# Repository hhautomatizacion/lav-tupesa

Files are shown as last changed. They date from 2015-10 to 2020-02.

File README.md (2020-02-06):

<br/>
<p align="center">
  
</p>
<br/>

# lav-tupesa

## Fecha 
* 2015

## Descripcion del proyecto
* Control de lavadora industrial tupesa 190

## Herramientas utilizadas
* KGL_WIN version 3.66
* DopSoft version 1.01.08

## Modelos PLC, etc.
* PLC LS Master K 120S K7M-DR40U
* HMI Delta DOP B05S111 
* Modulo Analogo G7F-R2D

## Autores
* <a href="http://www.github.com/pedrohermon">pedrohermon</a> 
* <a href="http://www.github.com/emmanuel156">emmanuel156</a> 

## Comentarios
* Ninguno

## Contenido
* Carpeta de Diagramas
	* Diagramas del proyecto
		* Diagramas electricos
		* Diagramas de bloques
		* Dibujos
* Carpeta de Documentos
	* Documentos pensados para el usuario final
		* Manuales de usuario
		* Manuales de programacion
* Carpeta de Fotos
	* Fotos del proyecto antes, durante y despues del desarrollo del mismo
		* Fotos
		* Capturas de pantalla
* Carpeta de Historial
	* Documentacion del desarrollo del proyecto
		* Hojas de datos de componentes
		* Manuales de usuario de componentes
		* Documentacion de funciones, herramientas
* Carpeta de Programas
	* Programas de Computadora, PLC, etc. 
		* Codigos fuente
		* Iconos e imagenes usados en los programas 
		* Archivos de configuracion de los programas
		* Programas compilados
* Carpeta de Pruebas
	* Pruebas preliminares del proyecto
		* Programas incompletos, o secciones de programas
		* Capturas de comunicacion
		* Modelos de componentes que se hayan probado

---
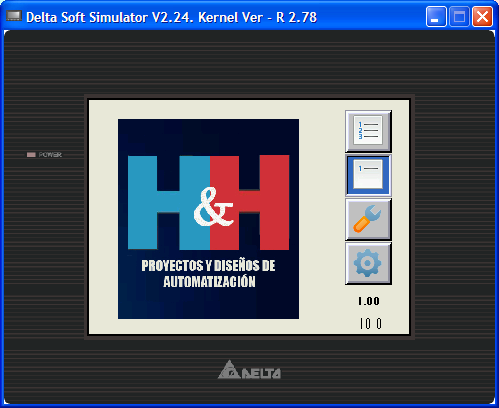
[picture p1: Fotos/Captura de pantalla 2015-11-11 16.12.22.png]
Captura de pantalla 2015-11-11 16.12.22.png

---
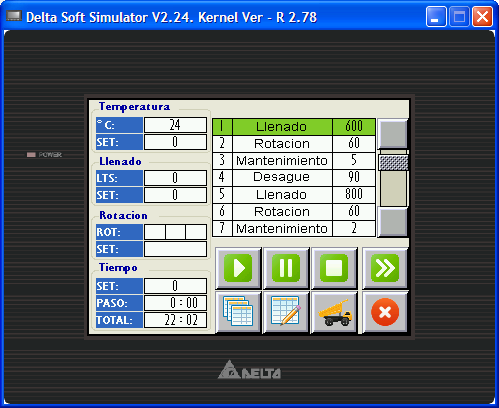
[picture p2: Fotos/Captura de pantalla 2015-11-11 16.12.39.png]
Captura de pantalla 2015-11-11 16.12.39.png

---
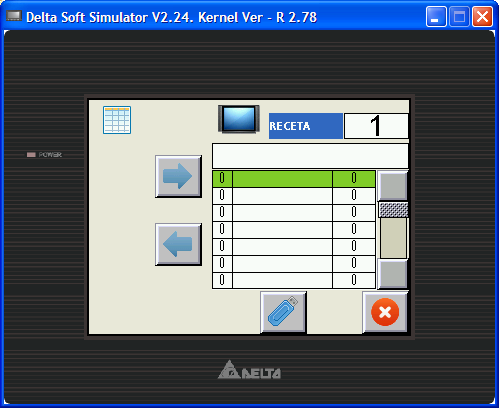
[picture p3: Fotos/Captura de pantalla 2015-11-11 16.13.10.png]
Captura de pantalla 2015-11-11 16.13.10.png

---
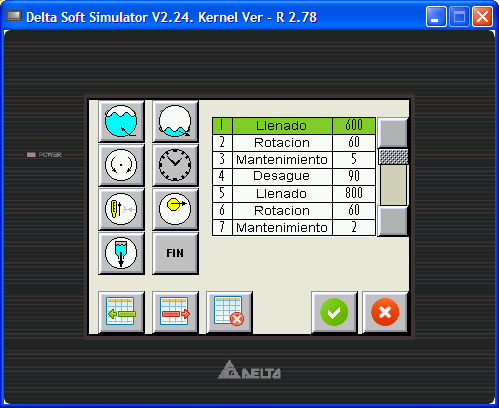
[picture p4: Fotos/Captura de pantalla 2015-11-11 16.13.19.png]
Captura de pantalla 2015-11-11 16.13.19.png

---
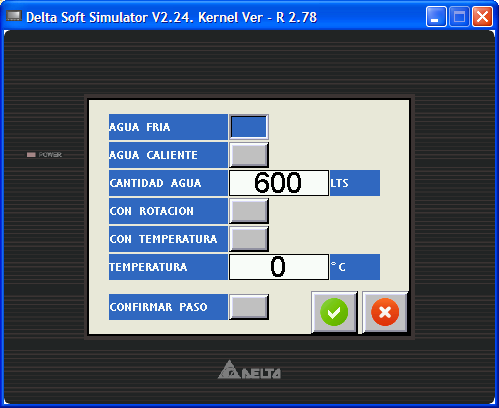
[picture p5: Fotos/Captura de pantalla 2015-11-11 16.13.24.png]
Captura de pantalla 2015-11-11 16.13.24.png

---
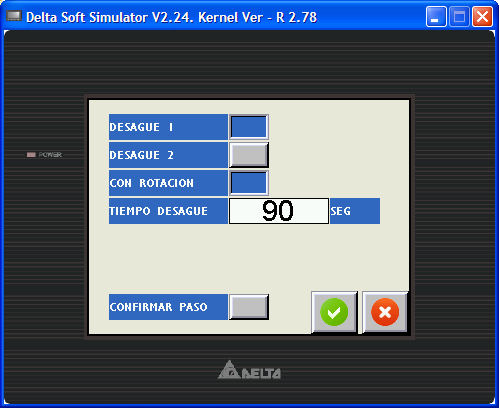
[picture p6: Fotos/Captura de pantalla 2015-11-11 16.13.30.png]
Captura de pantalla 2015-11-11 16.13.30.png

---
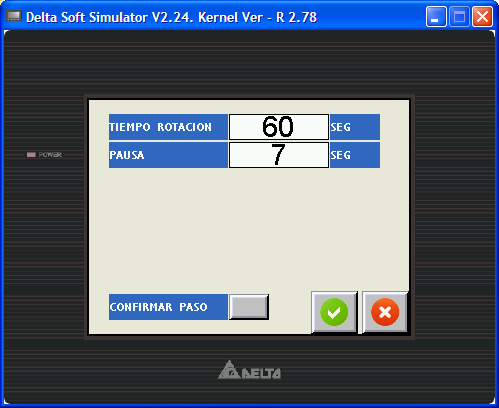
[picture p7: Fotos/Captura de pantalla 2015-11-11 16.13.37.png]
Captura de pantalla 2015-11-11 16.13.37.png

---
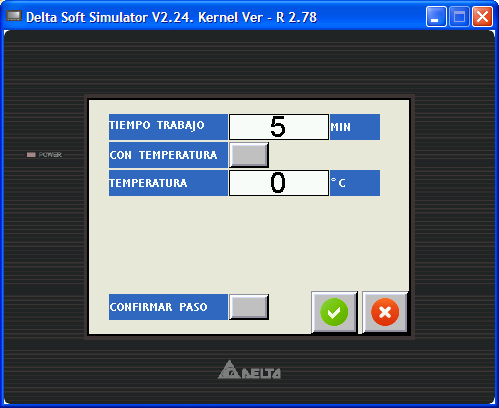
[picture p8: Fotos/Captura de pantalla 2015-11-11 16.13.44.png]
Captura de pantalla 2015-11-11 16.13.44.png

---
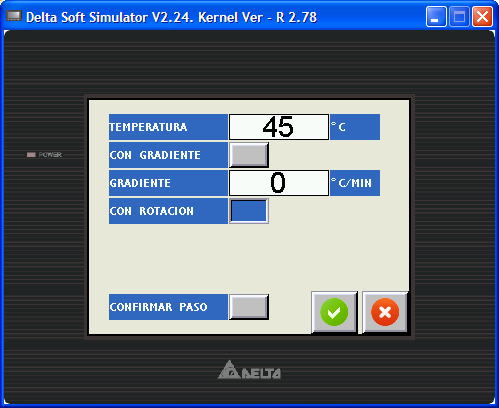
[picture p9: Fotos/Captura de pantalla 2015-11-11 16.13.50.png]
Captura de pantalla 2015-11-11 16.13.50.png

---
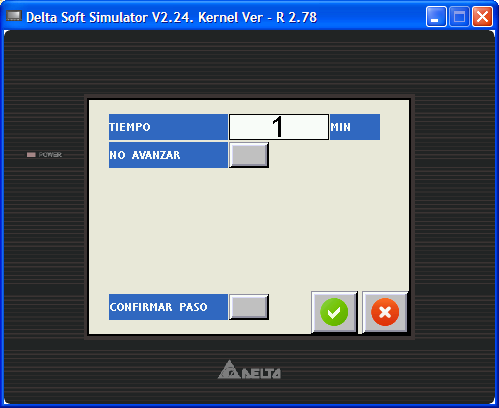
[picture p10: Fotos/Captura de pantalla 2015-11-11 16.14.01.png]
Captura de pantalla 2015-11-11 16.14.01.png

---
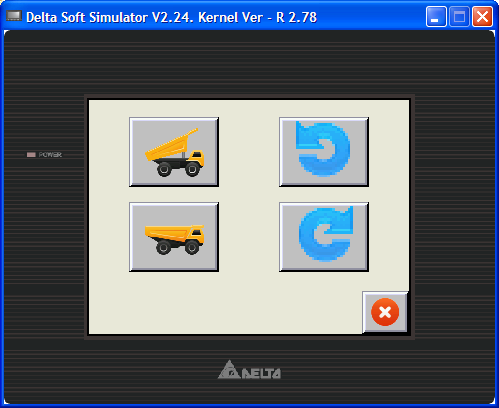
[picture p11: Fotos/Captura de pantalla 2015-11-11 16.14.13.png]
Captura de pantalla 2015-11-11 16.14.13.png

---
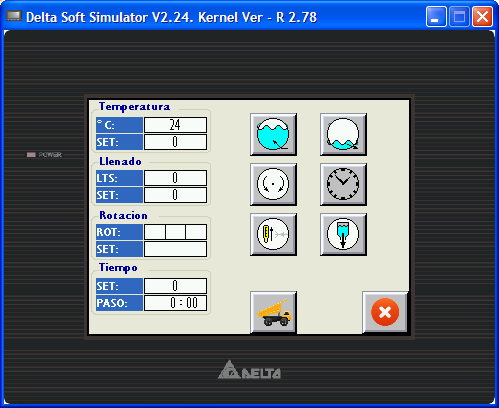
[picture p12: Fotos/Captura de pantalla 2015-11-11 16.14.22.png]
Captura de pantalla 2015-11-11 16.14.22.png

---
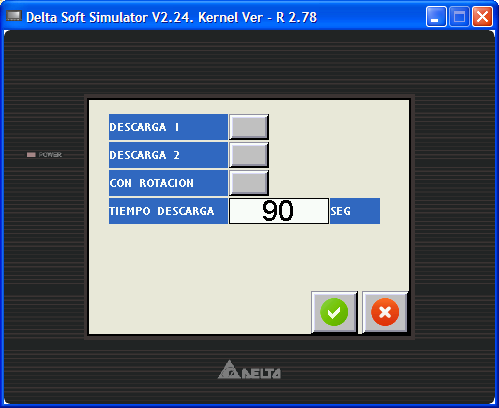
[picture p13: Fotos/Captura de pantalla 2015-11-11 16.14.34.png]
Captura de pantalla 2015-11-11 16.14.34.png

---
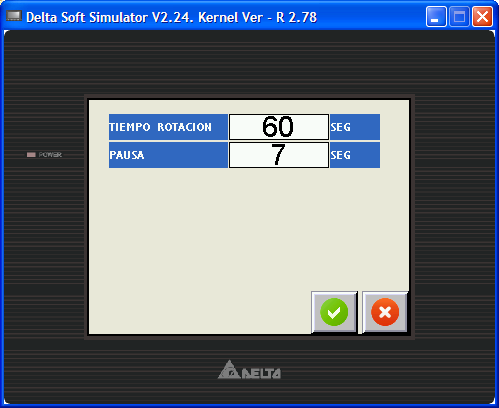
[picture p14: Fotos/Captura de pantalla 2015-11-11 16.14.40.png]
Captura de pantalla 2015-11-11 16.14.40.png

---
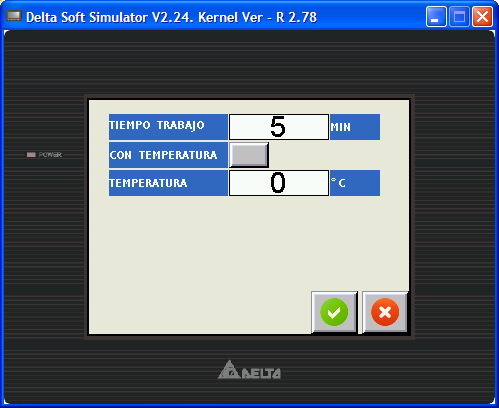
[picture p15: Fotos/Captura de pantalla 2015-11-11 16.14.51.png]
Captura de pantalla 2015-11-11 16.14.51.png

---
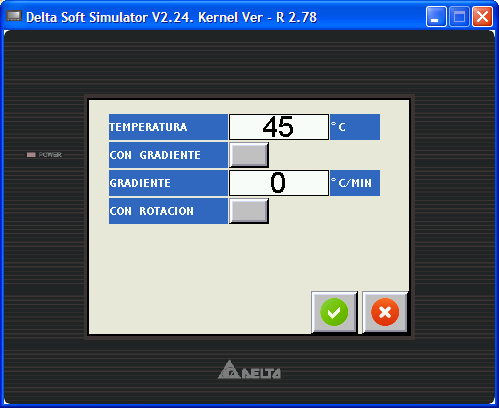
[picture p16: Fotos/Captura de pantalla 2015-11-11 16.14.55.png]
Captura de pantalla 2015-11-11 16.14.55.png

---
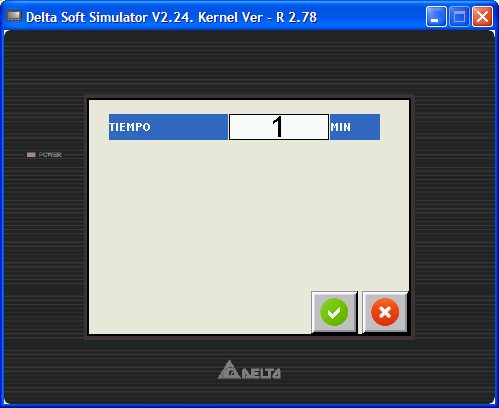
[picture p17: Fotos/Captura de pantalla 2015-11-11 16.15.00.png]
Captura de pantalla 2015-11-11 16.15.00.png

---
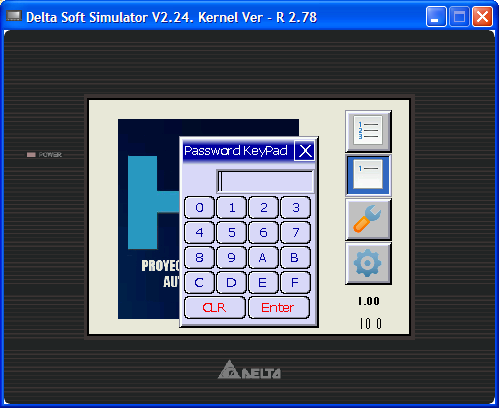
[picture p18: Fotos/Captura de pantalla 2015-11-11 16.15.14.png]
Captura de pantalla 2015-11-11 16.15.14.png

---
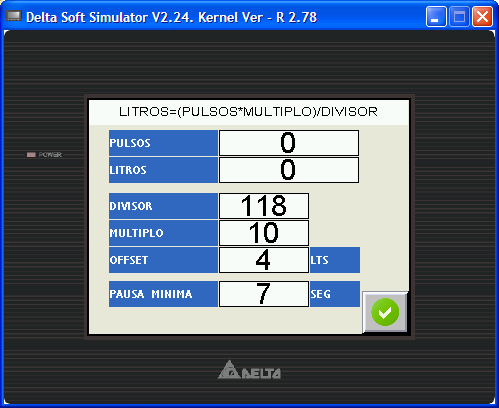
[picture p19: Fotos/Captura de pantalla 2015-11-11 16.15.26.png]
Captura de pantalla 2015-11-11 16.15.26.png

---
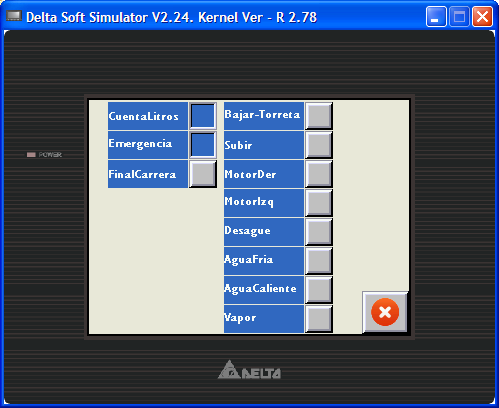
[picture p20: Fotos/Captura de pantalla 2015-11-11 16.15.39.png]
Captura de pantalla 2015-11-11 16.15.39.png

---
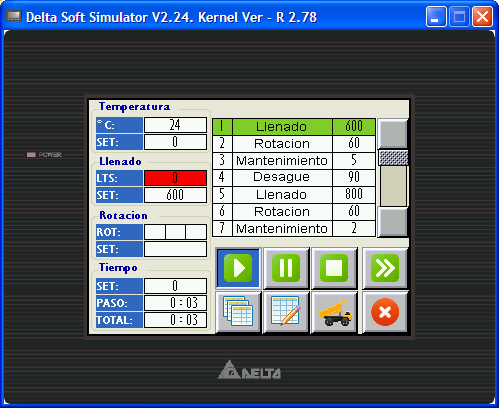
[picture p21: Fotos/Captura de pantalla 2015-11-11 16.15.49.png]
Captura de pantalla 2015-11-11 16.15.49.png

---
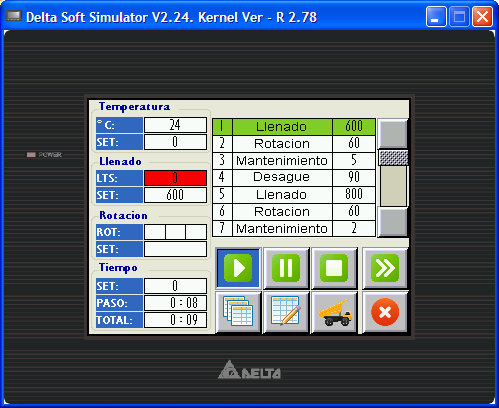
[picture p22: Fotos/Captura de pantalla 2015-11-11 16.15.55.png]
Captura de pantalla 2015-11-11 16.15.55.png

---
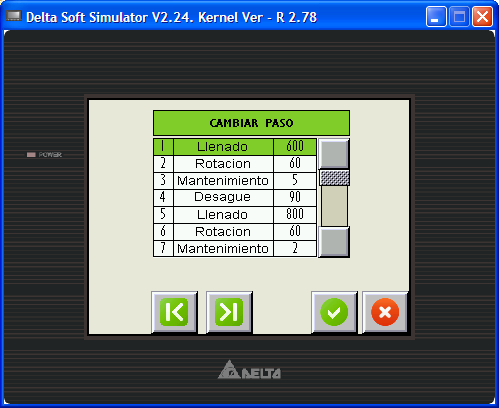
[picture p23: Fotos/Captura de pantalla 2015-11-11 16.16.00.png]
Captura de pantalla 2015-11-11 16.16.00.png

---
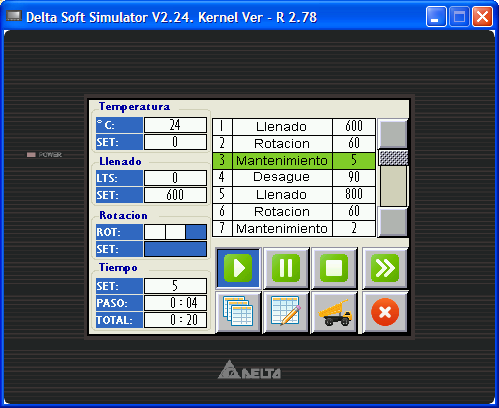
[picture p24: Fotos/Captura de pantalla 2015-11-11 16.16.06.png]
Captura de pantalla 2015-11-11 16.16.06.png

---
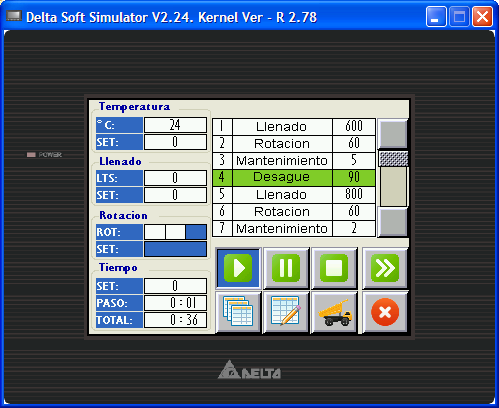
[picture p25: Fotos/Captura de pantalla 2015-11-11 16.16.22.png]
Captura de pantalla 2015-11-11 16.16.22.png

---
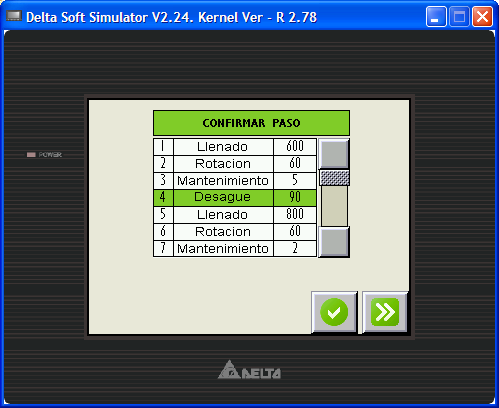
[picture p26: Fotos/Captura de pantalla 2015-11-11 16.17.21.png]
Captura de pantalla 2015-11-11 16.17.21.png

---
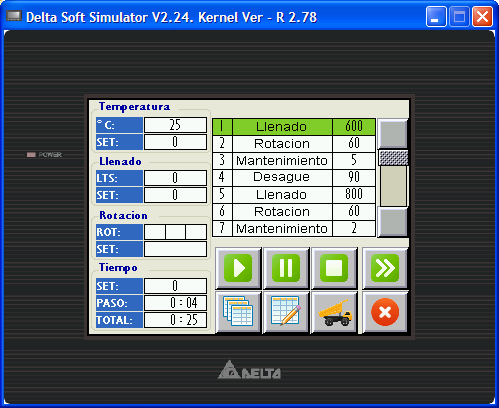
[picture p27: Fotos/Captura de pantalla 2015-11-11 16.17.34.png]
Captura de pantalla 2015-11-11 16.17.34.png

---
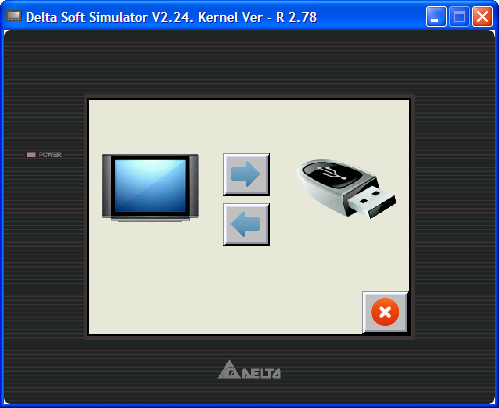
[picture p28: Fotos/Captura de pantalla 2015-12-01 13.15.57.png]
Captura de pantalla 2015-12-01 13.15.57.png

---
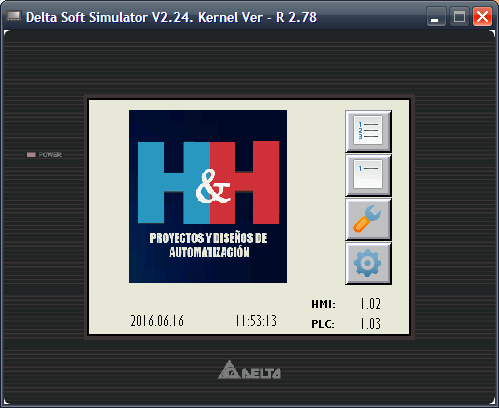
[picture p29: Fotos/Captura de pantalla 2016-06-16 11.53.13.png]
Captura de pantalla 2016-06-16 11.53.13.png

---
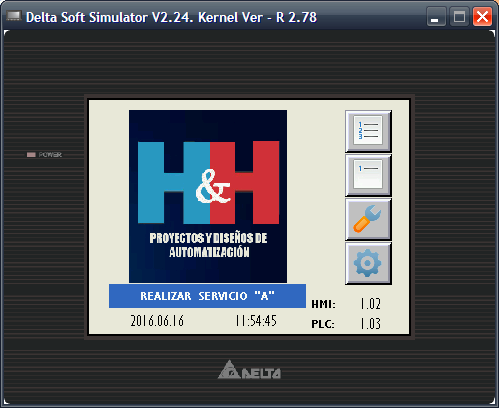
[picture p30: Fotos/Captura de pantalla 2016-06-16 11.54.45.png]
Captura de pantalla 2016-06-16 11.54.45.png

---
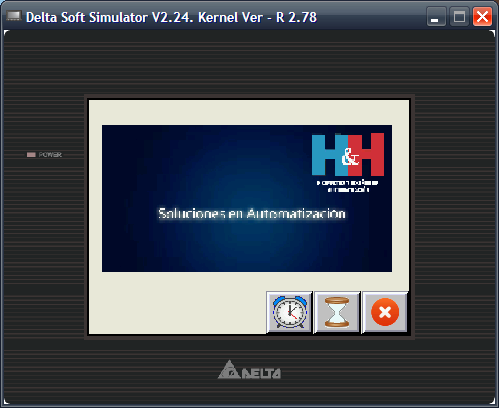
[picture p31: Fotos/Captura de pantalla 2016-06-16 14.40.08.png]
Captura de pantalla 2016-06-16 14.40.08.png

---
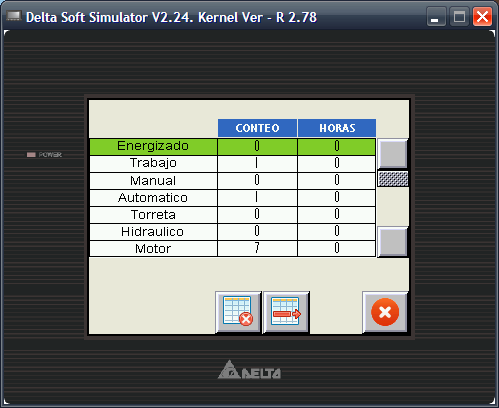
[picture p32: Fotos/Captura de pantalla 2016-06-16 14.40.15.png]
Captura de pantalla 2016-06-16 14.40.15.png

---
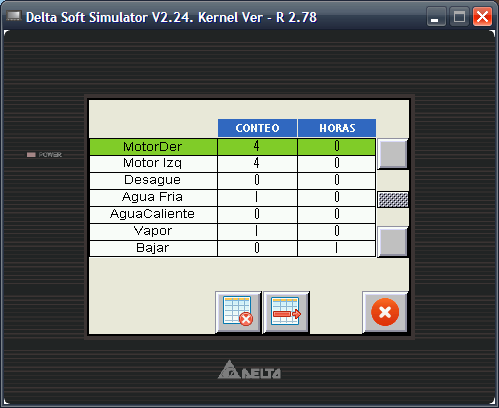
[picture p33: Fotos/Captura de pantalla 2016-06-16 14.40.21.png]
Captura de pantalla 2016-06-16 14.40.21.png

---
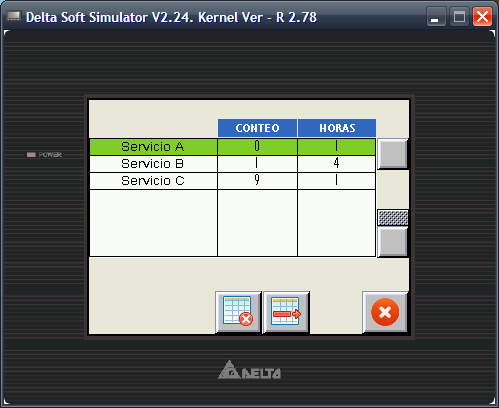
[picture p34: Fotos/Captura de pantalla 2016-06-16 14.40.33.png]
Captura de pantalla 2016-06-16 14.40.33.png

---
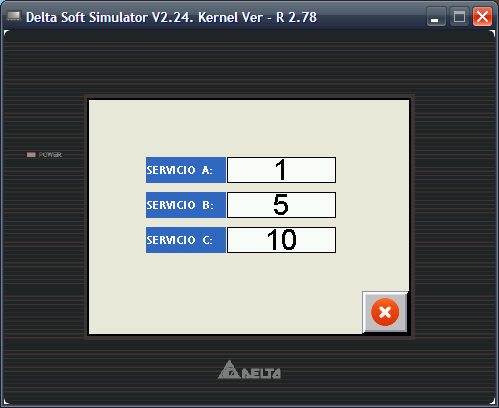
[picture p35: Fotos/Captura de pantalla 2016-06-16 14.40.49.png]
Captura de pantalla 2016-06-16 14.40.49.png

---
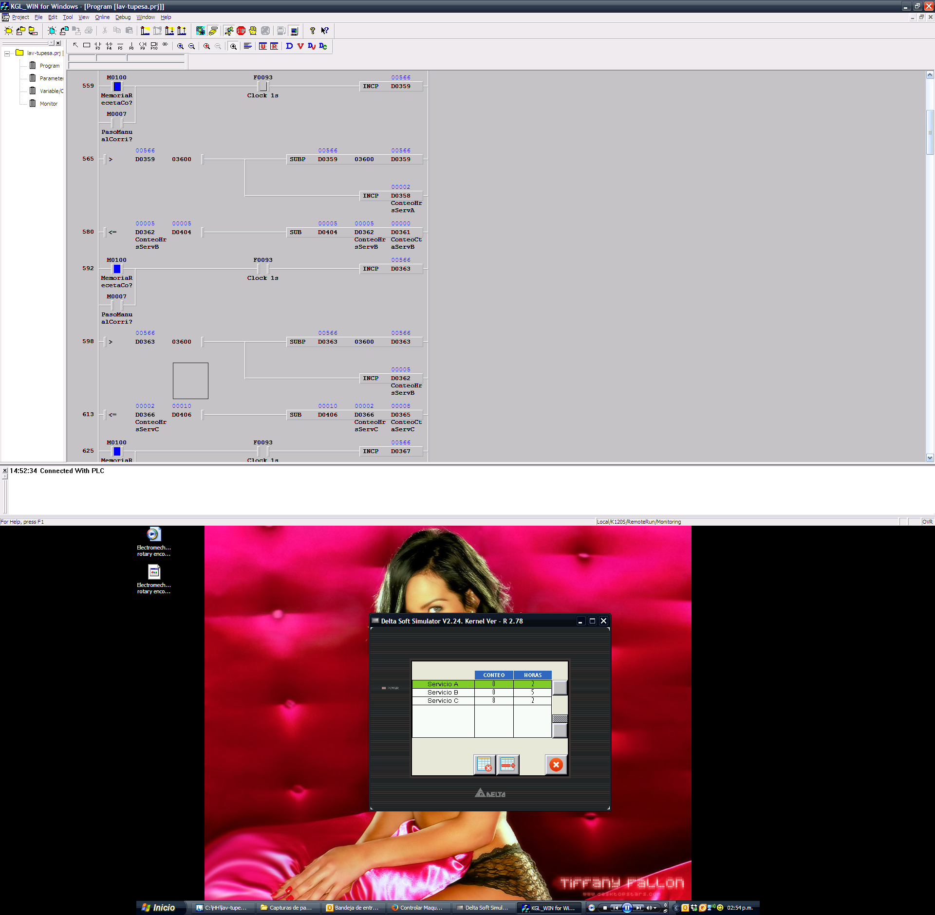
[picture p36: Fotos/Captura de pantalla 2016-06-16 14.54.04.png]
Captura de pantalla 2016-06-16 14.54.04.png

---
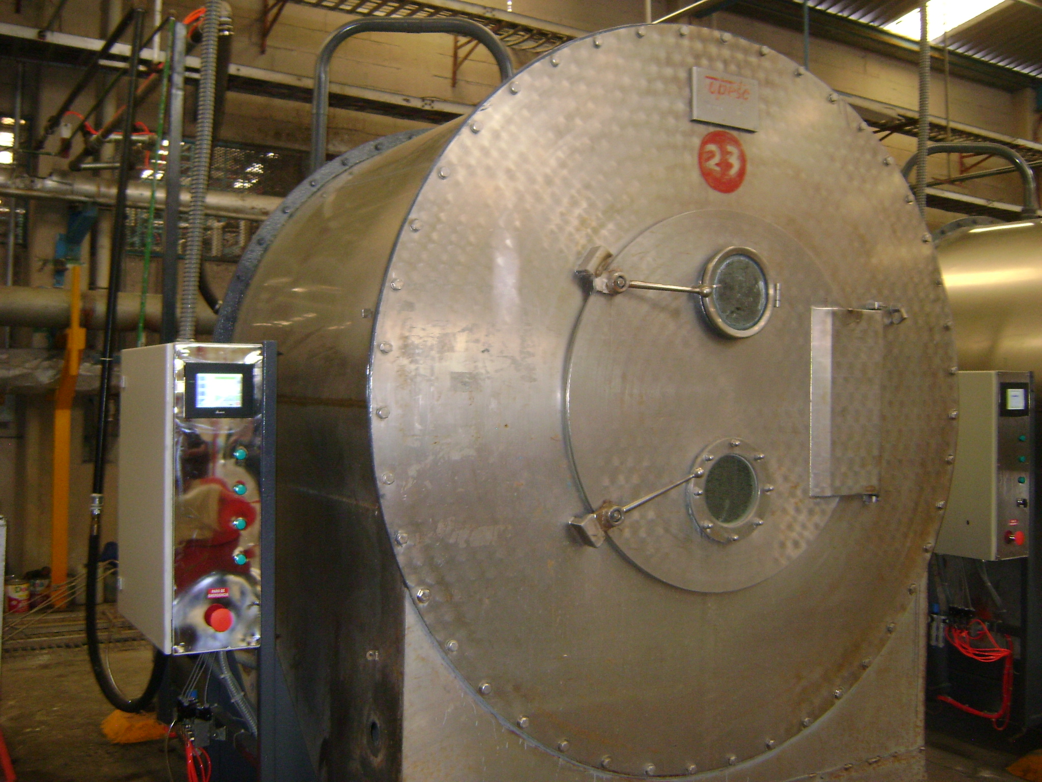
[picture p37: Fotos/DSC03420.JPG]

---
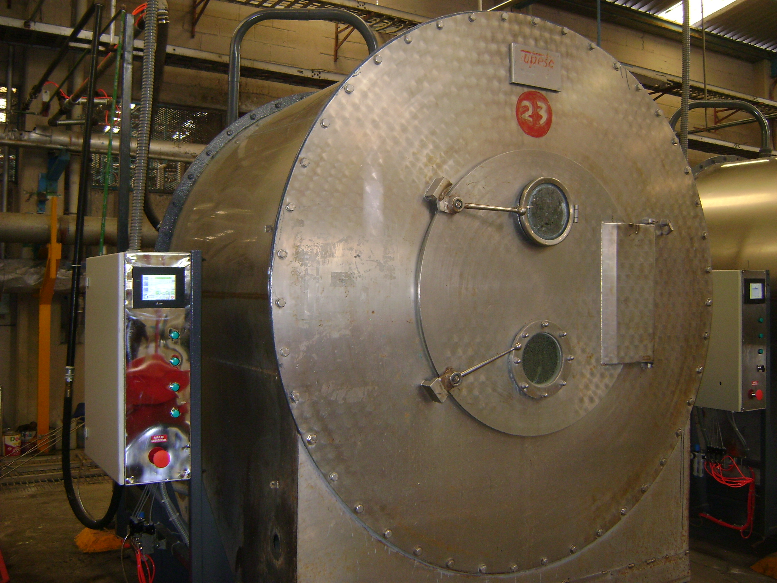
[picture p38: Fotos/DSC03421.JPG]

---
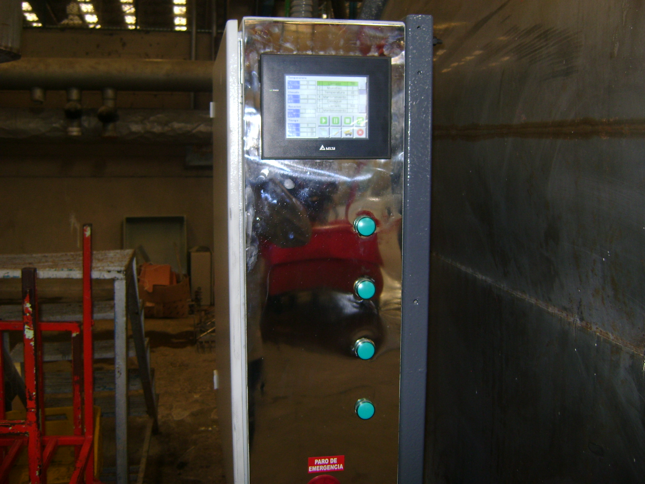
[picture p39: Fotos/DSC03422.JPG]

---
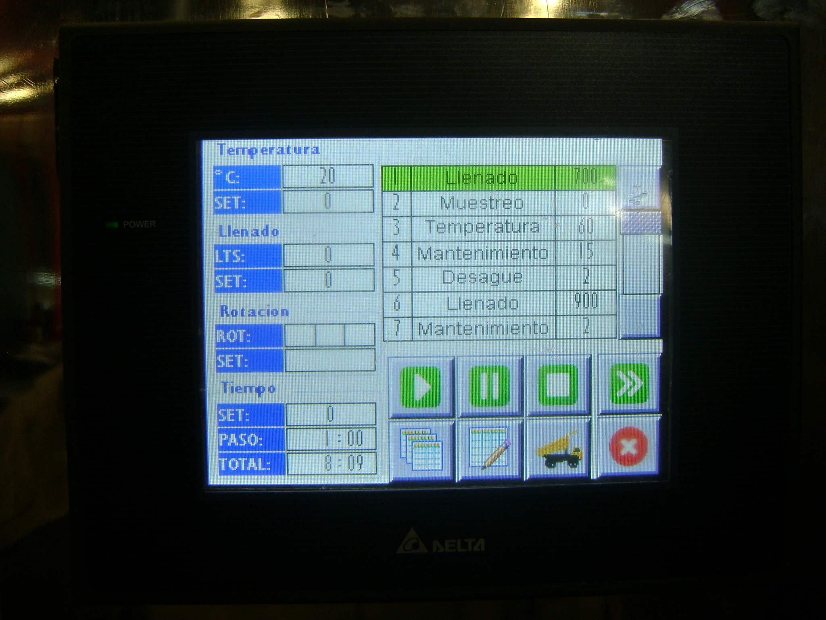
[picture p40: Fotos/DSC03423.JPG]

---

---

---

---

---

---

---

---

---

---

---

---

---

---

---

---
Network (2).png
---
alarm clock.png
---

---

---

---

---

---

---

---

---

---

---

---

---

---

---

---

---

---

---

---

---

---

---

---

---

---

---

---

---

---

---

---

---

---

---

---

---

---

---

---

---

---

---

---

---
example diagram for wiring with a PLC input.JPG
---

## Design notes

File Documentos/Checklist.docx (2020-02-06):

# Checklist

Conexiones HMI

- Alimentación de 24v correctamente atornillada
- Comunicación serial correctamente atornillada

Conexiones PLC

- Alimentación de 220v correctamente atornillada
- Revisar accionamiento de final de carrera volquete
- Revisar Sentido de giro de motor
- Revisar accionamiento Pistón Desagüe
- Revisar accionamiento Válvula Agua fría
- Revisar accionamiento Válvula Agua caliente
- Revisar accionamiento Válvula Agua tratada
- Revisar accionamiento Válvula Vapor
- Revisar accionamiento Bomba cubeta de químicos
- Revisar accionamiento de Bomba hidráulica volquete

Programación HMI

- Revisar tamaño de Teclado de entrada de datos
- Revisar parámetros de funcionamiento

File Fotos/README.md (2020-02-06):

<br/>
<p align="center">
  
</p>
<br/>

# Carpeta de Fotos

## Fotos del proyecto antes, durante y despues del desarrollo del mismo

* Fotos

* Capturas de pantalla

---
Captura de pantalla 2015-11-11 16.12.22.png
---
Captura de pantalla 2015-11-11 16.12.39.png
---
Captura de pantalla 2015-11-11 16.13.10.png
---
Captura de pantalla 2015-11-11 16.13.19.png
---
Captura de pantalla 2015-11-11 16.13.24.png
---
Captura de pantalla 2015-11-11 16.13.30.png
---
Captura de pantalla 2015-11-11 16.13.37.png
---
Captura de pantalla 2015-11-11 16.13.44.png
---
Captura de pantalla 2015-11-11 16.13.50.png
---
Captura de pantalla 2015-11-11 16.14.01.png
---
Captura de pantalla 2015-11-11 16.14.13.png
---
Captura de pantalla 2015-11-11 16.14.22.png
---
Captura de pantalla 2015-11-11 16.14.34.png
---
Captura de pantalla 2015-11-11 16.14.40.png
---
Captura de pantalla 2015-11-11 16.14.51.png
---
Captura de pantalla 2015-11-11 16.14.55.png
---
Captura de pantalla 2015-11-11 16.15.00.png
---
Captura de pantalla 2015-11-11 16.15.14.png
---
Captura de pantalla 2015-11-11 16.15.26.png
---
Captura de pantalla 2015-11-11 16.15.39.png
---
Captura de pantalla 2015-11-11 16.15.49.png
---
Captura de pantalla 2015-11-11 16.15.55.png
---
Captura de pantalla 2015-11-11 16.16.00.png
---
Captura de pantalla 2015-11-11 16.16.06.png
---
Captura de pantalla 2015-11-11 16.16.22.png
---
Captura de pantalla 2015-11-11 16.17.21.png
---
Captura de pantalla 2015-11-11 16.17.34.png
---
Captura de pantalla 2015-12-01 13.15.57.png
---
Captura de pantalla 2016-06-16 11.53.13.png
---
Captura de pantalla 2016-06-16 11.54.45.png
---
Captura de pantalla 2016-06-16 14.40.08.png
---
Captura de pantalla 2016-06-16 14.40.15.png
---
Captura de pantalla 2016-06-16 14.40.21.png
---
Captura de pantalla 2016-06-16 14.40.33.png
---
Captura de pantalla 2016-06-16 14.40.49.png
---
Captura de pantalla 2016-06-16 14.54.04.png
---

---

---

---

---
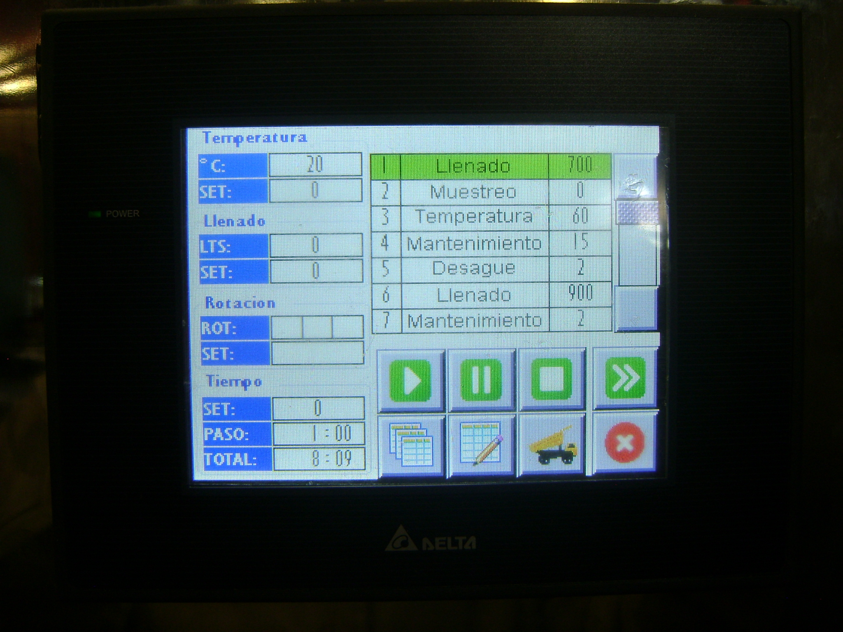
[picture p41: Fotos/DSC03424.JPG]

---
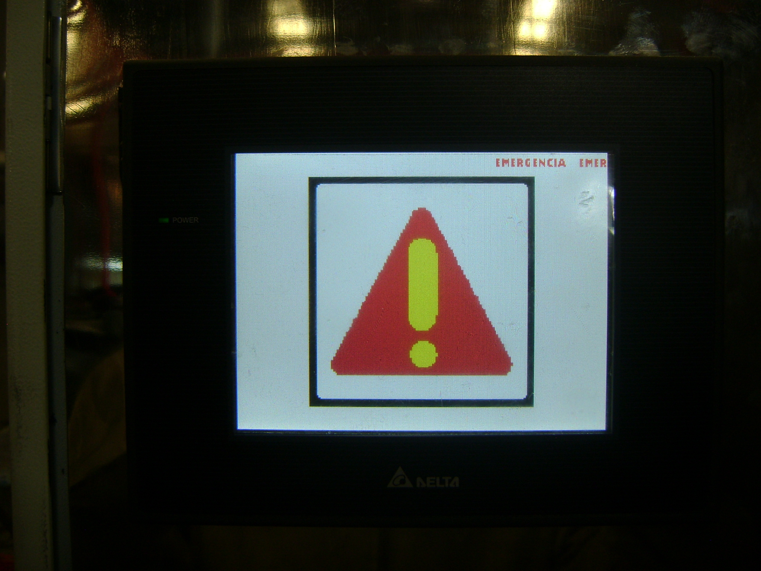
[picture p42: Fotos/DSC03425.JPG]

---
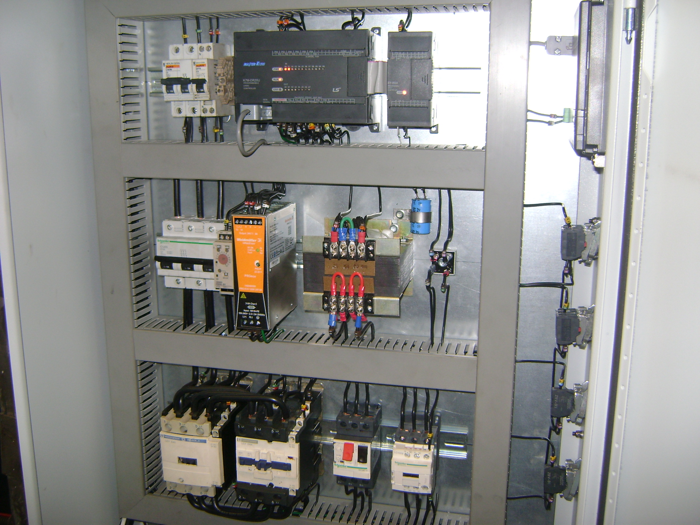
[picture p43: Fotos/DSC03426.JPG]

---
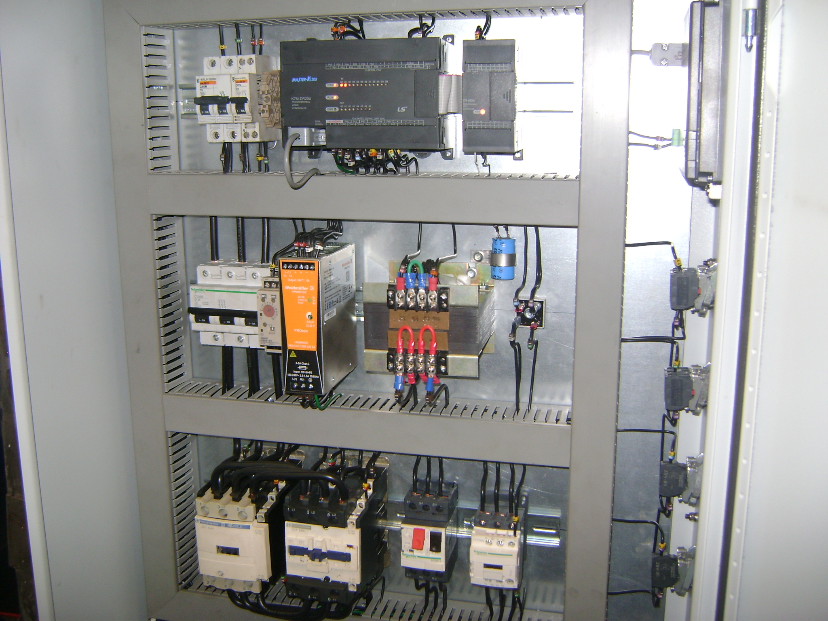
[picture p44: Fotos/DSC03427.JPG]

---
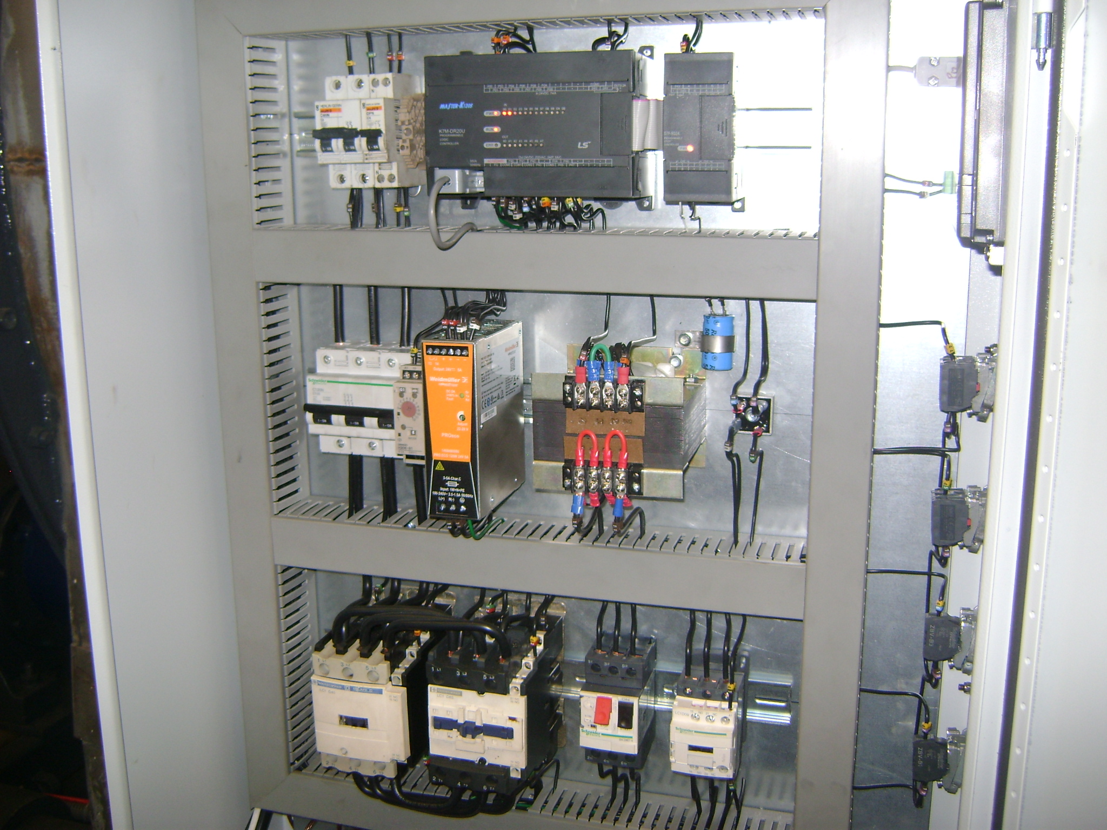
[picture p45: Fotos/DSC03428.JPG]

---
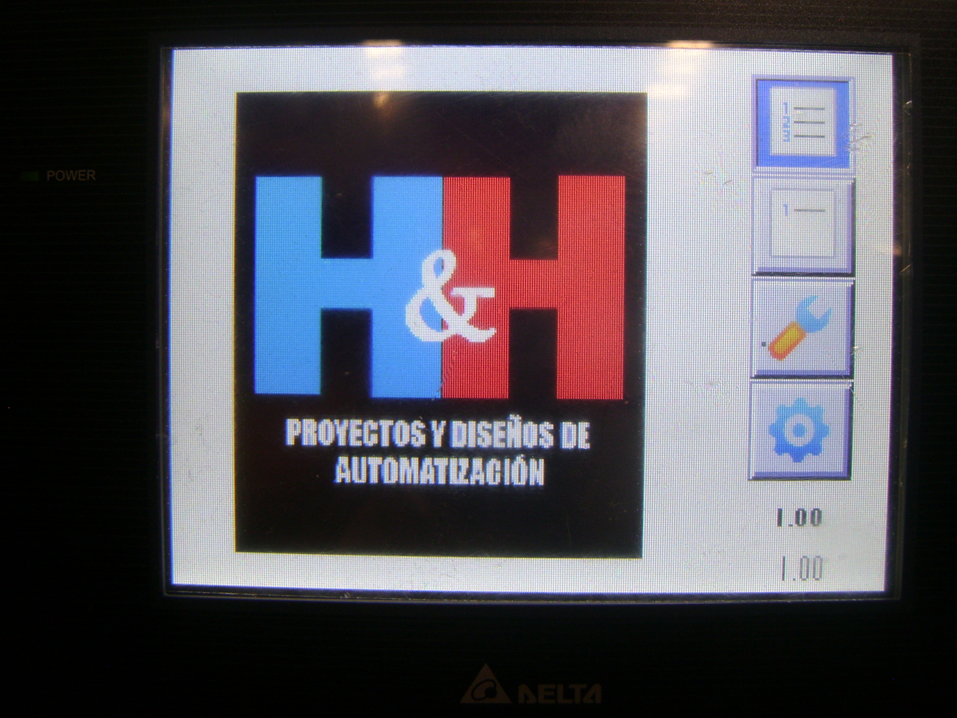
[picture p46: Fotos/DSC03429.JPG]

---
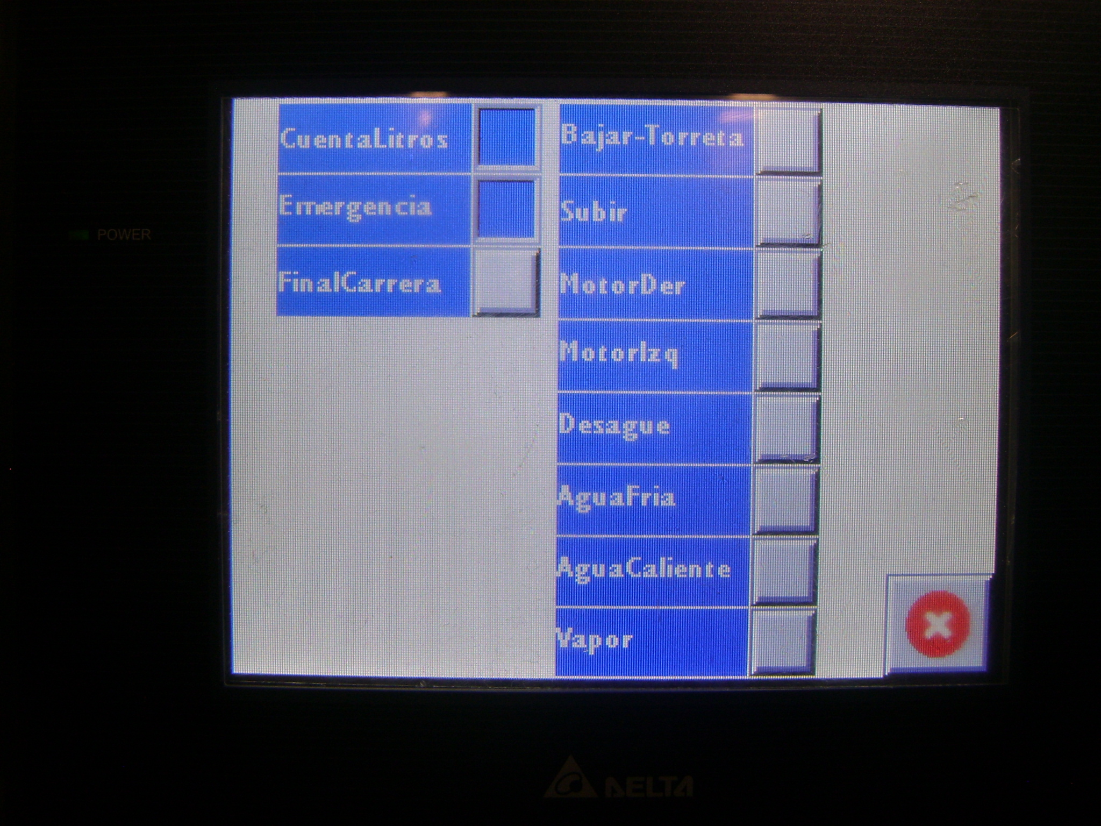
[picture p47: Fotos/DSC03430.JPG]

---
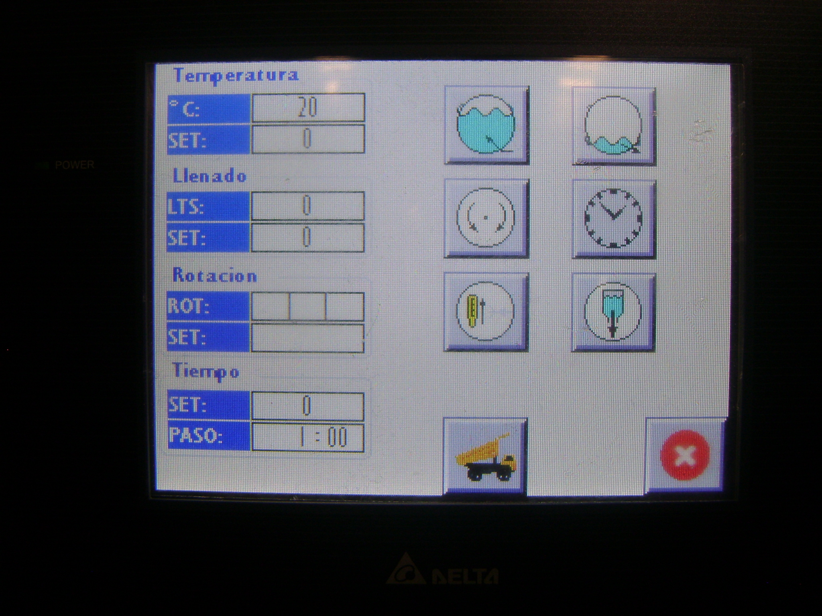
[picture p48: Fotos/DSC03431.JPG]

---
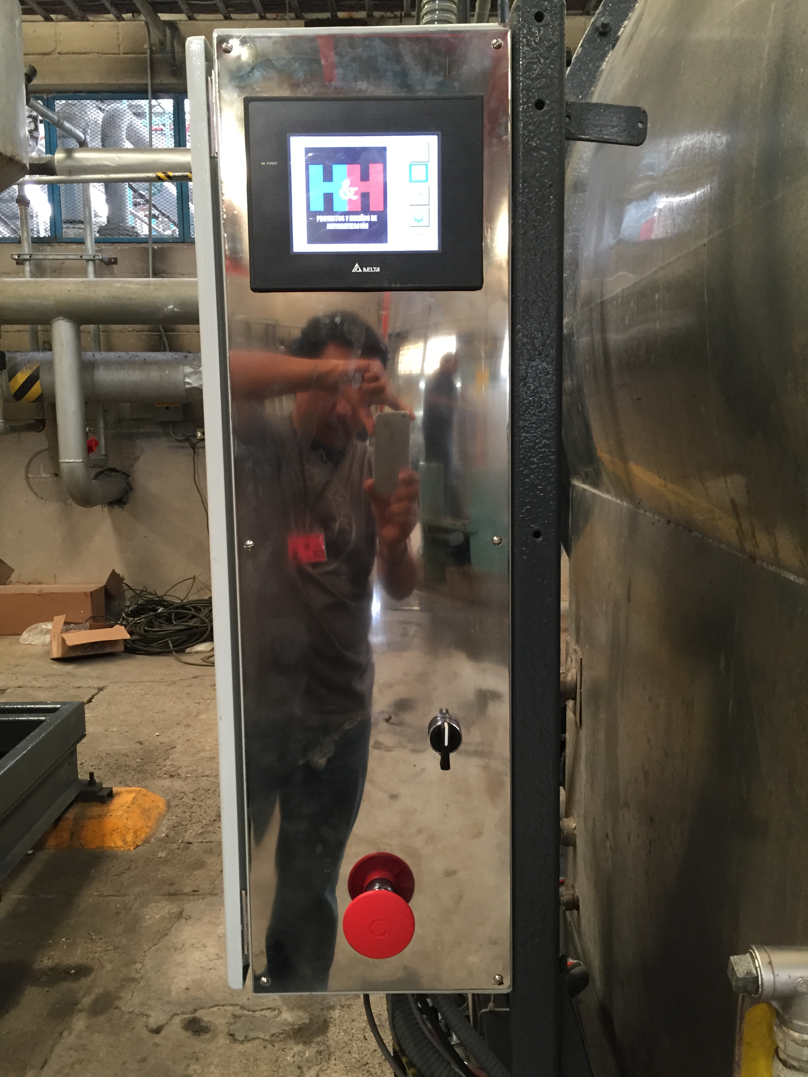
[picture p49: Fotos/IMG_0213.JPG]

---
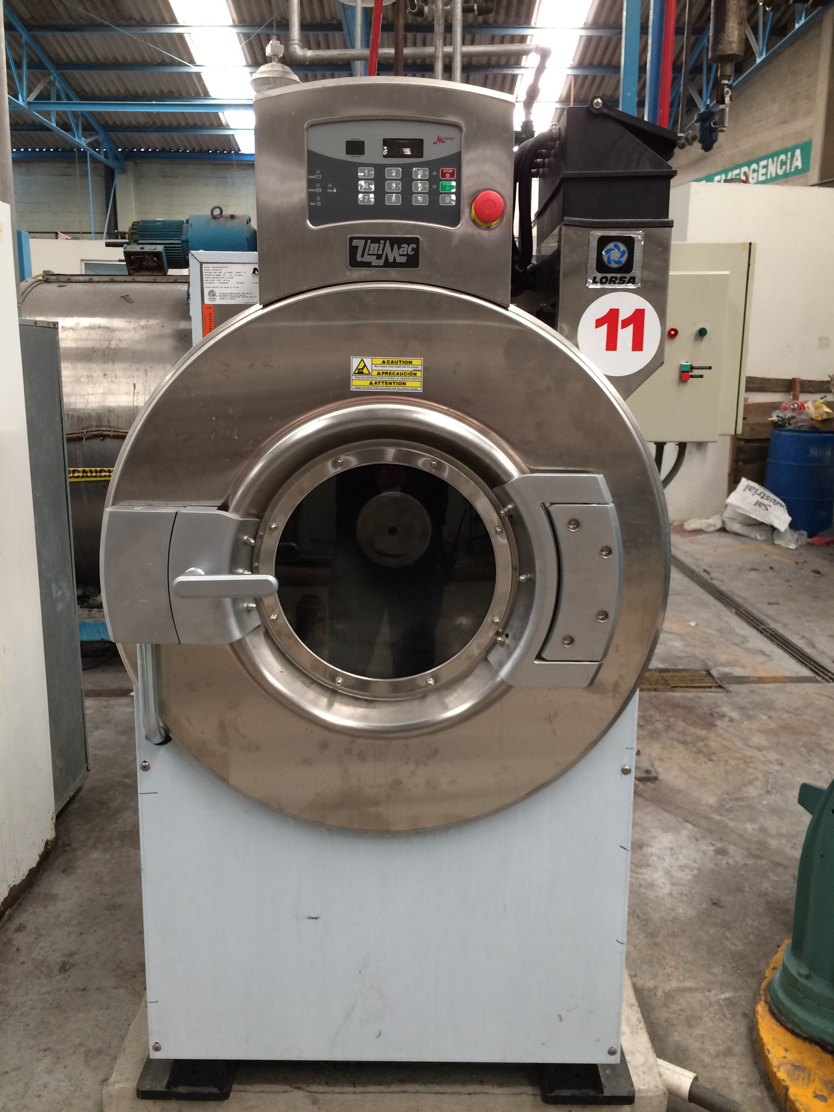
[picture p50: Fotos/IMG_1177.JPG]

---
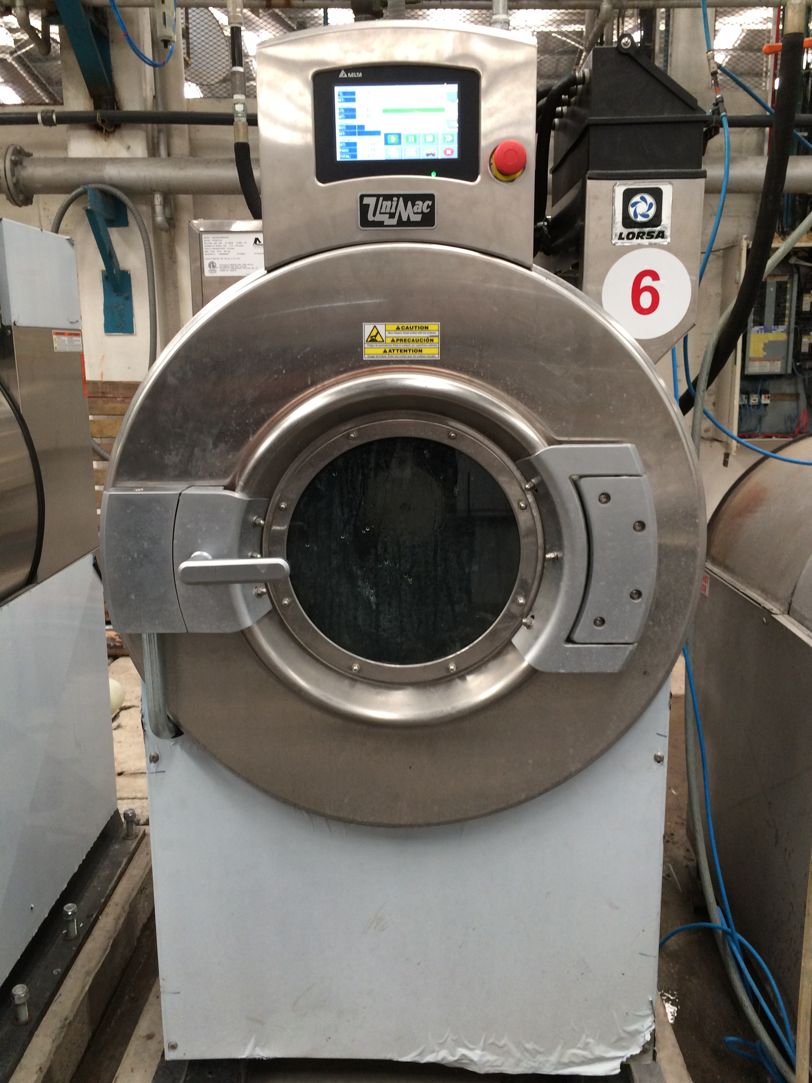
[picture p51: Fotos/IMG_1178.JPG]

---
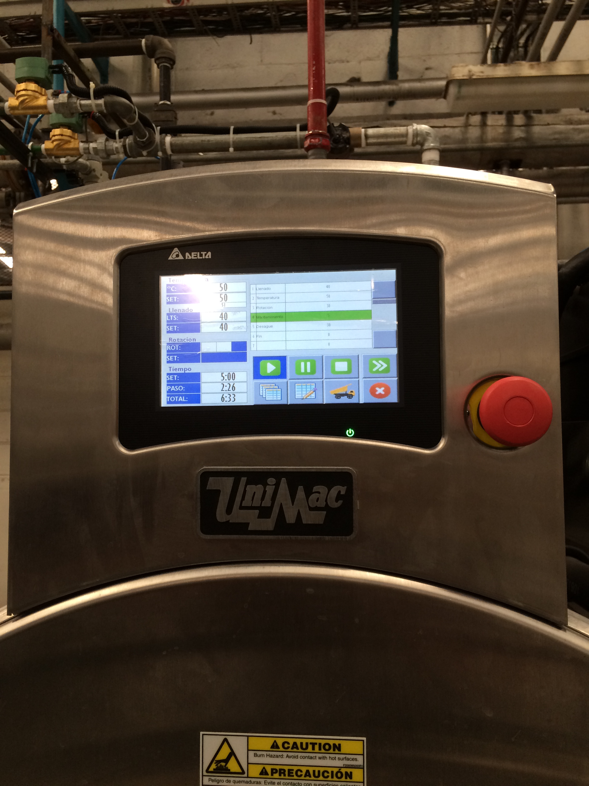
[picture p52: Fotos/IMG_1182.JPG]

---
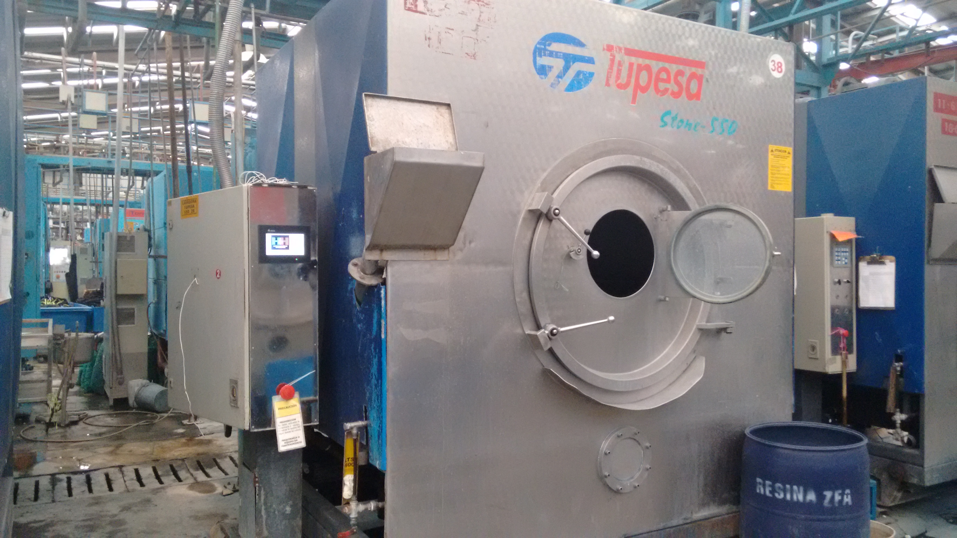
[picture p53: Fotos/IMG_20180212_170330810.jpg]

---

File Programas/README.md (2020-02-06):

<br/>
<p align="center">
  
</p>
<br/>

# Carpeta de Programas

## Programas de Computadora, PLC, etc. 

* Codigos fuente

* Iconos e imagenes usados en los programas 

* Archivos de configuracion de los programas

* Programas compilados

---
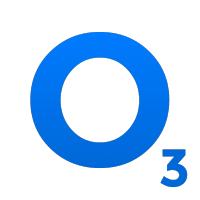
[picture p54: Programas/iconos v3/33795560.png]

---
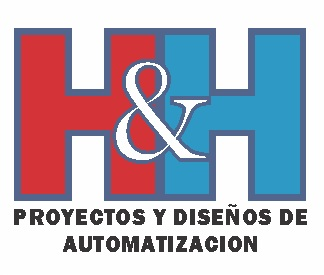
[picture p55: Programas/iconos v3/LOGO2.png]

---
Network (2).png
---
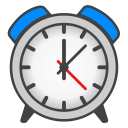
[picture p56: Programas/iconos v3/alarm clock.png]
alarm clock.png

---

---

---

---

---

---

---

---

---

---

---

---

---

---

---

---

---

---

---

---

---

---

---

---

---

---
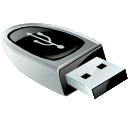
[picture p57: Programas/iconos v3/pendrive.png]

---

---

---
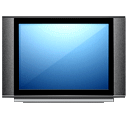
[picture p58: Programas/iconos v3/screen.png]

---

---

---

---

---

---

---

---

---

---

---

---

---

---
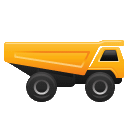
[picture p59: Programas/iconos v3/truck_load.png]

---
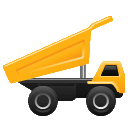
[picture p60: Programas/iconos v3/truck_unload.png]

---

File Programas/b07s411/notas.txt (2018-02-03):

No editar!

Editar la version para dop-b05s111 y de ahi convertir. No olvidar cambiar el tamaño de texto de los grid a 22 pixeles.

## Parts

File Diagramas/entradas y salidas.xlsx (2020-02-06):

Programa lav-tupesa
Lista de entrada y salidas del PLC
P00 | CuentaLitros | P40 | Torreta
P01 | ParoEmergencia (NC) | P41 | Volquete
P02 | MaquinaArriba | P42 | GiroDerecha
P03 | MaquinaHorizontal | P43 | GiroIzquierda
P04 | MaquinaAbajo | P44 | Desague
P05 | PuertaAbierta | P45 | AguaFria
P06 | PuertaCerrada | P46 | AguaCaliente
P07 |  | P47 | Vapor
P08 |  | P48 | Bajar maquina
P09 |  | P49 | SegurosPuerta
P0A |  | P4A | IntroducirQuimicos
P0B |  | P4B | EnjuagueQuimicos
P0C |  | P4C | VelocidadCentrifuga
P0D |  | P4D | FrenoTombola
P0E |  | P4E | GeneradorOzono
P0F |  | P4F | QuemadorOzono
P11
P12
P13
P14
P15
P16
P17
Modulo analogo RTD
CH0 | PT100
CH1
CH2
CH3
Modulo analogo
CH0 |  | CH0 | Generador Ozono
CH1

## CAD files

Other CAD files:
Diagramas/Diagrama Maquina Milnor Laboratorio Teñido.dwg
Pruebas/simula-lavadora/simula lavadora.dwg
Diagramas/Diagrama Lav. Unimac modelo UWL045K1MXU4P01. lab. Teñido.dwg
Diagramas/Diagrama Tupesa 190.dwg

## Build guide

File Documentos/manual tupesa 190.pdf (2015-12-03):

1

## Introducción

El controlador puede funcionar en modo automático (siguiendo una lista de pasos) en donde se

pueden almacenar 50 recetas de hasta 100 pasos cada una.

También es posible copiar las recetas a una memoria USB para transferirlas de una maquina a

otra.

El controlador dispone de tres espacios de memoria, uno donde se encuentra la lista de pasos

con los que se está trabajando, otro donde se hace la edición de recetas y el último donde se encuentran

todas las recetas guardadas.

El controlador también puede funcionar en modo manual (realizar una acción a la vez), sin

necesidad de programar toda una receta para ejecutar una acción.

2

## Inicio

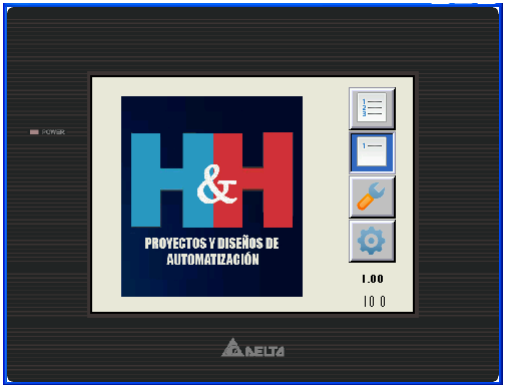
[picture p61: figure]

Al inicializar la maquina se presenta el menú de los diferentes modos de funcionamiento, así

como las páginas de configuración y pruebas de la misma.

Botón | Acción | Descripción

AUTOMATICO Entra al modo automático, donde la maquina ejecuta una serie de

| | pasos.
| MANUAL | Entra al modo manual ejecutando una acción a la vez.
CONFIG | Entra a la pantalla donde se modifican los parámetros de funcionamiento de la máquina.
TEST | Entra al modo de pruebas, donde se activan manualmente los actuadores de la máquina.

3

## Modo Automático

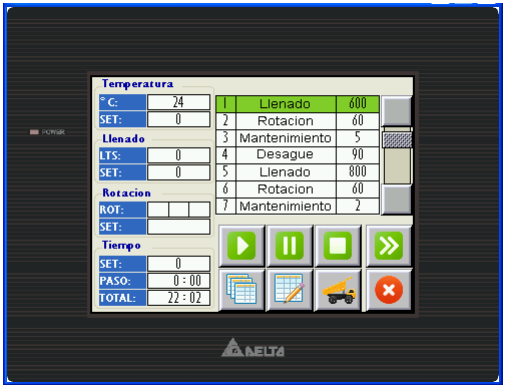
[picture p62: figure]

Presionando el botón “AUTOMATICO” | aparece la pantalla de funcionamiento automático,
en donde si ya hay una receta cargada al pulsar el botón “PLAY” | la maquina comienza a ejecutar

la receta.

4

## Modificar una receta

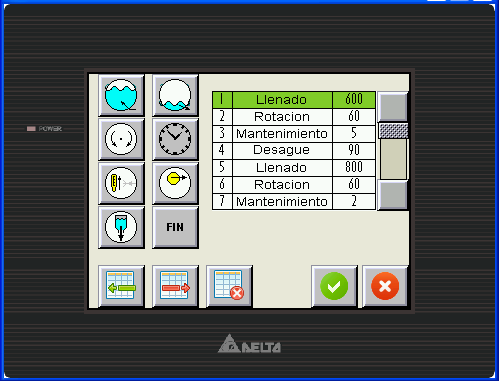
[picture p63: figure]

Al pulsar el botón de “EDITAR” el controlador copia los pasos de la receta actual al área

de memoria de edición, donde se pueden insertar los diferentes pasos de una receta así como establecer

sus opciones.

Del lado izquierdo se muestran los diferentes pasos que puede incluir en la receta que se está

editando.

Botón | Acción | Descripción
| LLENADO | Abre las válvulas de admisión de agua hasta que se llegue a la cantidad de agua programada. Se puede programar para que la canasta gire mientras entra agua, o que entre vapor mientras entra agua.

5

DESAGUE | Abre el desagüe de la maquina por el tiempo especificado. Se

puede programar que lo haga mientras la canasta gira.

ROTACION Configura los tiempos de rotación y pausa de la canasta de la

máquina (pero no hace que la canasta gire).

MANTENIMIENTO Mantiene | la | maquina trabajando | durante el tiempo

especificado. Si se programa con una temperatura el

programador mantiene dicha temperatura a lo largo de todo el

paso.

TEMPERATURA Introduce vapor a la canasta de la maquina hasta alcanzar la

temperatura programada. Si se programa con gradiente el

programador hace que el calentamiento sea gradual.

MUESTREO Hace una pausa en la ejecución de la receta para revisar el

estado de la carga. Después de la revisión se puede cambiar a

otro paso o hacer que la maquina trabaje por más tiempo.

QUIMICOS Hace que la canasta gire solo en un sentido durante el tiempo

especificado.

Del lado inferior izquierdo se encuentran los botones para insertar un paso, borrar un paso y

limpiar la receta.

Botón | Acción | Descripción
INSERTAR | Recorre el paso seleccionado y los que están debajo de él un

espacio hacia abajo.

BORRAR Borra el paso seleccionado y recorre los pasos debajo de él un

espacio hacia arriba.

6

LIMPIAR Inicializa la receta limpiando todos los pasos.

Del lado derecho se muestra una vista previa de la receta que está editando, así como el paso

que actualmente está editando.

Del lado inferior derecho se encuentra los botones “OK” | y “CANCEL” | , si presiona el

botón cancel los cambios que haya hecho en la receta no se guardan y se regresa a la pantalla anterior.

Cuando ha terminado las modificaciones a su receta, y al presionar el botón “OK” se copia

el contenido de la memoria de edición al espacio de memoria de la receta trabajando.

## Iniciar una receta

Para iniciar la ejecución de la receta trabajando basta con presionar el botón “PLAY” , con

esto la maquina ejecuta los pasos de la receta trabajando uno tras otro. Los contadores del tiempo total

de la receta y el paso comienzan a incrementarse. La ejecución se detendrá automáticamente al

encontrar un paso “FIN”.

## Pausar una receta

El botón “PAUSE” | pone en espera el paso que actualmente se está ejecutando. Para
reanudar la ejecución de la receta basta con presionar el botón “PAUSE” | por segunda vez o el
botón “PLAY” | .

7

## Saltar a otro paso en una receta

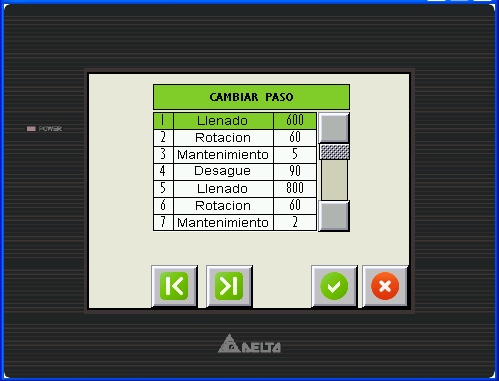
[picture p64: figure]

Se puede cambiar el paso en ejecución de la receta en cualquier momento; basta con presionar

el botón “FF” | . Una vez en la pantalla “CAMBIAR PASO” seleccione el paso al que quiere llegar
y presione el botón “OK” | .
También pueden utilizar los botones “PREV” | y “NEXT” | para saltar rápidamente al

paso anterior y siguiente respectivamente.

## Detener una receta

Al presionar el botón “STOP” se detiene la ejecución de la receta actual y se regresa al

inicio de la receta.

8

## Manejo de recetas

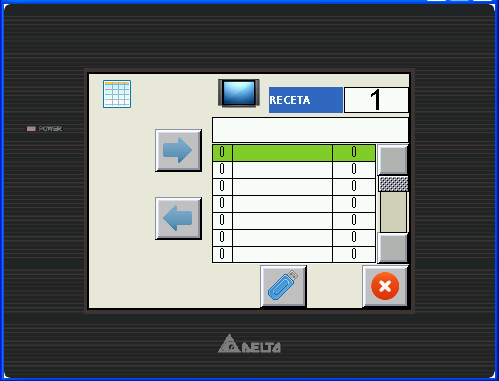
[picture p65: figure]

Al presionar el botón “RECETAS” aparece la pantalla de manejo de recetas. En esta

pantalla se puede cargar una receta guardada al área de memoria de receta trabajando o guardar la

receta trabajando para reutilizarla después.

Botón | Acción | Descripción
RECETA | De 1 a 50 | Es el espacio de memoria de recetas seleccionado actualmente. Debajo se muestra los pasos que hay actualmente en el espacio de memoria.
| GUARDAR | Guarda los pasos de la receta trabajando en el espacio de memoria seleccionado.
| CARGAR | Carga el espacio de memoria seleccionado a la receta trabajando.

9

USB | Entra a la pantalla para importar o exportar las recetas para
| intercambiarlas entre maquinas.

## Importar/Exportar recetas

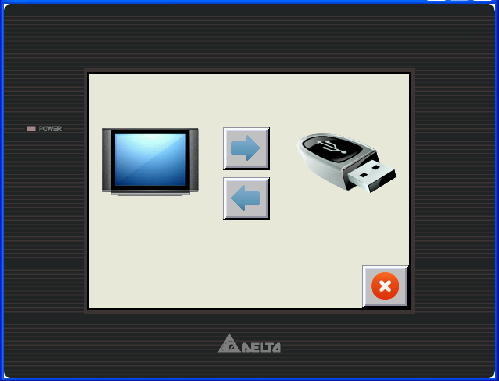
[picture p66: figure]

Al presionar el botón “USB” aparece la pantalla para importar o exportar las recetas. Si

una memoria USB ha sido conectada a la pantalla del programador, un icono muestra que la memoria

esta lista para realizar la transferencia de las recetas.

Botón | Acción | Descripción
| EXPORTAR | Copia todas las recetas a la memoria USB, sobrescribiendo el archivo si ya existe.
| IMPORTAR | Copia todas las recetas del USB al controlador, sobre escribiendo las recetas existentes.

10

## Modo Manual

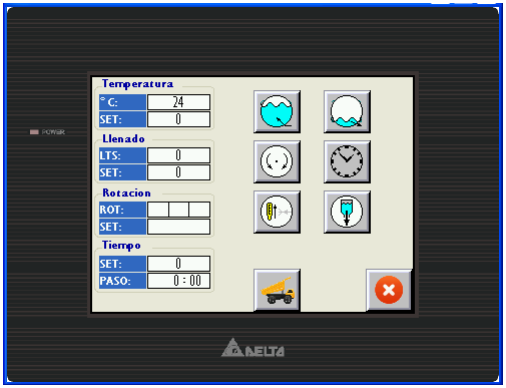
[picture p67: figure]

Para entrar al modo de funcionamiento manual presione el botón “MANUAL” . En modo

manual se puede ocupar las funciones de la maquina sin necesidad de crear una receta completa.

Botón | Acción | Descripción
| LLENADO | Abre las válvulas de admisión de agua hasta que se llegue a la cantidad de agua programada. Se puede programar para que la canasta gire mientras entra agua, o que entre vapor mientras entra agua.
| DESAGUE | Abre el desagüe de la maquina por el tiempo especificado. Se puede programar que lo haga mientras la canasta gira.

11

ROTACION Configura los tiempos de rotación y pausa de la canasta de la

máquina (pero no hace que la canasta gire).

MANTENIMIENTO Mantiene | la | maquina trabajando | durante el tiempo

especificado. Si se programa con una temperatura el

programador mantiene dicha temperatura a lo largo de todo el

paso.

TEMPERATURA Introduce vapor a la canasta de la maquina hasta alcanzar la

temperatura programada. Si se programa con gradiente el

programador hace que el calentamiento sea gradual.

QUIMICOS Hace que la canasta gire solo en un sentido durante el tiempo

especificado.

## Ejecutar una acción

Por ejemplo, para introducir agua a la maquina basta con presionar el botón de

“LLENADO” | , configurar la cantidad de agua, etc. y confirmar presionando “OK” | para que la

maquina empiece a llenarse de agua.

## Cancelar una acción

Para cancelar una acción basta con presionar el botón de la acción que quiere cancelar y que

actualmente se está ejecutando, con esto puede cambiar los parámetros de la acción o cancelarla por

completo al presionar el botón “CANCEL” .

12

## Contraseña

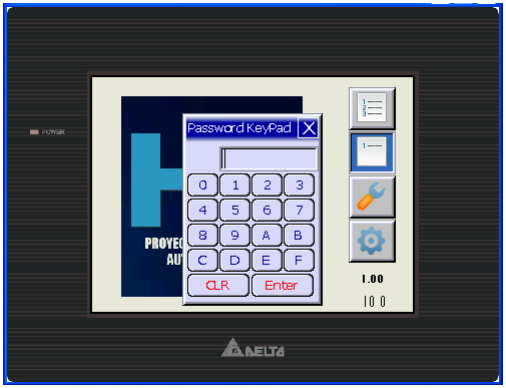
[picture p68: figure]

Por seguridad el controlador pide una contraseña para entrar a las pantallas de configuración y

de pruebas de la máquina. Esto tiene la finalidad de evitar que personal no autorizado modifique los

parámetros de funcionamiento de la máquina lo que podría ocasionar mal funcionamiento.

13

## Configuración

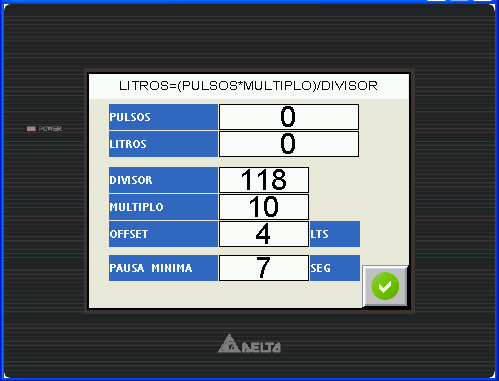
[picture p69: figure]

Para entrar a la pantalla de configuración presione el botón “CONFIG” . En la pantalla

configuración se pueden modificar los parámetros de funcionamiento de la máquina. La pantalla

muestra los siguientes campos donde usted colocará los valores que mejor se adapten a la

configuración de su máquina.

Opción | Descripción
PULSOS | Muestra el estado actual del contador de pulsos de la entrada de agua. Este valor se

vuelve a cero después de realizar una acción de “DESAGUE”.

LITROS | Muestra el resultado del cálculo del volumen de agua (siguiendo la fórmula que se

muestra en la parte superior de la pantalla).

14

DIVISOR | Parámetro para el cálculo del volumen de agua siguiendo la fórmula que se muestra en la parte superior de la pantalla.
MULTIPLO | Parámetro para el cálculo del volumen de agua siguiendo la fórmula que se muestra en la parte superior de la pantalla.
OFFSET | Es la cantidad de agua que se restara al volumen programado en el que se cerraran las válvulas para impedir que entre más agua a la máquina. Este parámetro tiene la finalidad de compensar la cantidad de agua que se queda en la tubería una vez que el actuador se ha cerrado. (Unidades: Litros)
PAUSA MINIMA | Es el tiempo mínimo de pausa entre que el motor de la maquina deja de girar hacia una sentido y comienza a girar hacia el sentido contrario. (Unidades: Segundos)

15

## Test

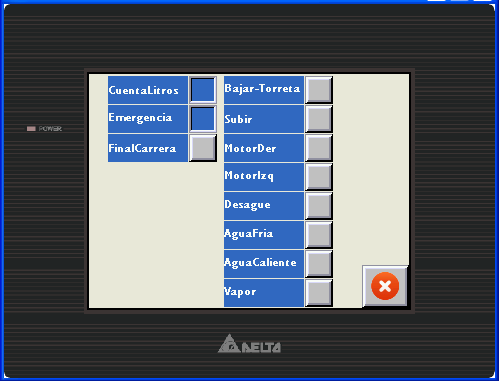
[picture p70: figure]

El controlador dispone de un modo especial llamado test al cual se entra presionando el botón

“TEST” , este modo tiene la finalidad de realizar pruebas para ayudar a solucionar problemas de

funcionamiento de la máquina.

En la pantalla se muestra el estado de los sensores de la maquina (lado izquierdo de la pantalla)

y se pueden activar manualmente las salidas del controlador (lado derecho de la pantalla).

Para activar una salida simplemente presione el botón situado junto al actuador que necesita

probar.

16

## Índice

INTRODUCCIÓN | 1
INICIO | 2
MODO AUTOMÁTICO | 3
MODIFICAR UNA RECETA | 4
INICIAR UNA RECETA | 6
PAUSAR UNA RECETA | 6
SALTAR A OTRO PASO EN UNA RECETA | 7
DETENER UNA RECETA | 7
MANEJO DE RECETAS | 8
IMPORTAR/EXPORTAR RECETAS | 9
MODO MANUAL | 10
EJECUTAR UNA ACCIÓN | 11
CANCELAR UNA ACCIÓN | 11
CONTRASEÑA | 12
CONFIGURACIÓN | 13
TEST | 15
ÍNDICE | 16

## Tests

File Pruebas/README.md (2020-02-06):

<br/>
<p align="center">
  
</p>
<br/>

# Carpeta de Pruebas

## Pruebas preliminares del proyecto

* Programas incompletos, o secciones de programas

* Capturas de comunicacion

* Modelos de componentes que se hayan probado

---
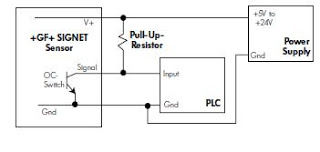
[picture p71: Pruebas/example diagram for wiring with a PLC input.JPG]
example diagram for wiring with a PLC input.JPG

---

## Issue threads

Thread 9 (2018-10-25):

Cuando se desconecta PT100, no presenta mensaje de error

pedrohermon, 2018-10-25:
Cuando el sensor presenta problemas, el plc se queda con el valor de temperatura anterior a la falla!

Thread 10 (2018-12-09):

Desarrollar editor de recetas para PC

itzayana157, 2018-12-09:
Que no se pueda seleccionar archivo, sino unidad de disco, la cual siempre leera el archivo que busca la hmi (con la estructura de archivos adecuada).

Arrastrando y soltando para copiar.

Cambiar nombre y borrar con click derecho.

Tipo total comander.

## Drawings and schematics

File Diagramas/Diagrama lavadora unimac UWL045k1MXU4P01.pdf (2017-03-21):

FG

19

20

24V | A | b | B

MOD: G7F-RD2A, MARCA: LS

MODULO RTD

-RS485 + | PLC MOD: K7M-DR40U/DC MARCA: LS | 24G | 24V

### SALIDA

### MOD: DOP-B05S111 MARCA: DELTA

ELECTRONICS, INC.

+24V | PANTALLA TACTIL
19 | 0V

20

EQUIPO:

Equipo: Lavadora Textil
Marca: Unimac
Modelo:
Maquina: Unimac, Laboratorio Teñido

Representa cable.

Representa Borna de conexion.

Lista de dispositivos instalados:
1 pza. PLC Marca: Ls, Modelo: K7M-DR40U / DC
1 pza. Modulo analogo marca: Ls, Modelo: G7F-RD2A.
1 pza. Pantalla Tactil Marca: Delta electronics,inc. modelo: DOP-B07S411 1 pza. Fuente de alimentacion con salida a 24 VDC, 5 Amps.

NOTAS:

PROYECTO:

Adaptacion de sistema de control con PLC Marca: Ls y pantalla tactil Marca: Delta Electronics, inc.

o xx xx

xx

A | b | A | b
B | B | .
CH0 | CH1
24G | B | A CH3 | b CH2

RS232

2

3
5

7
4

5

Los voltajes opcionales de fuente.
Son por posibles cambios en la alimentacion de dispositivos, como por ejemplo: Bobinas de contactores, bobinas de electrovalvulas, etc. de ser así, hacer los cambios correspondientes.

0V +24V

20

19

G2

G3 | G4

G4

G1 Variador de velocidad.
G2 Pantalla HMI.
G3 PLC.
G4 Modulo Temperatura PLC. G5 Fuente de alimentacion. G6 Caudalimetro.

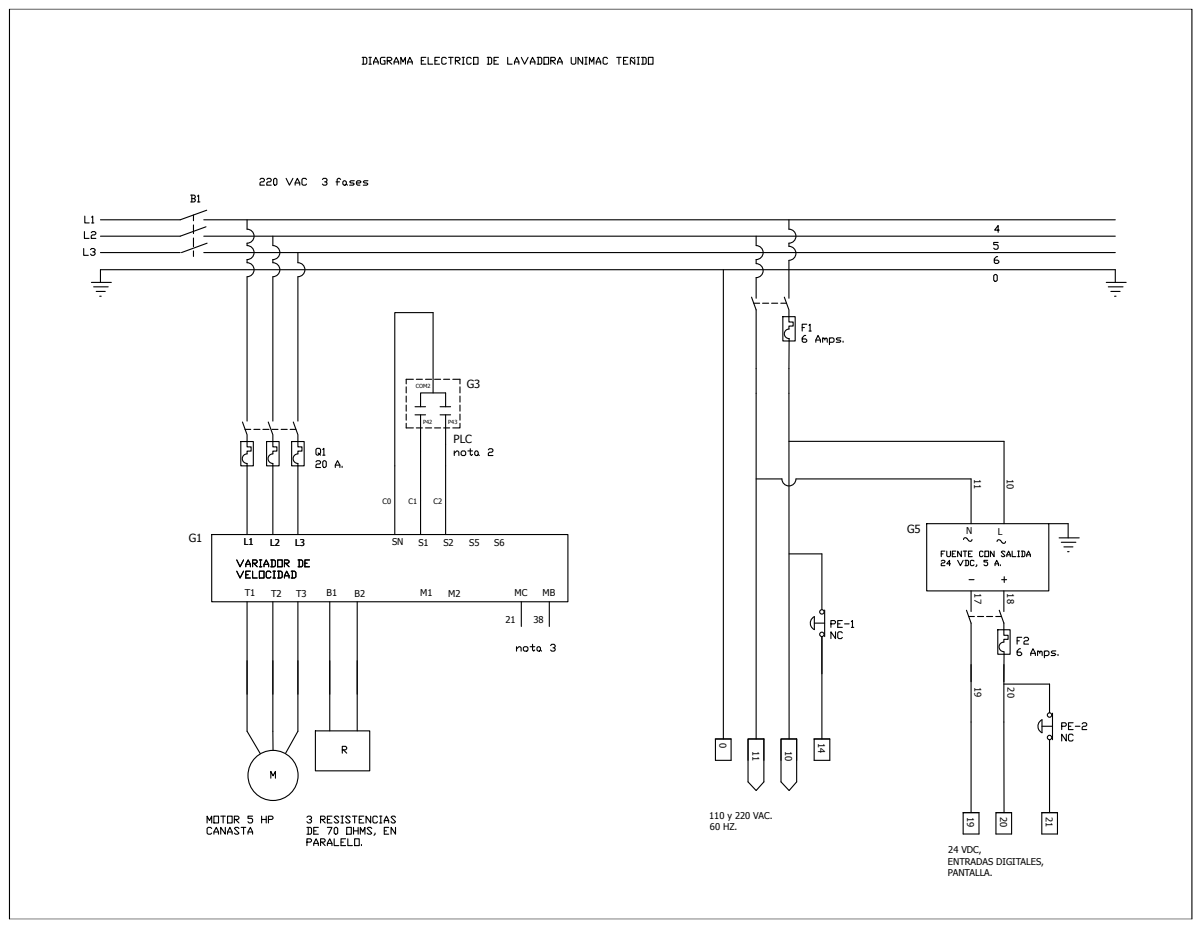
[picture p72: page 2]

# 19 ENTRADAS A ²⁴ VDC

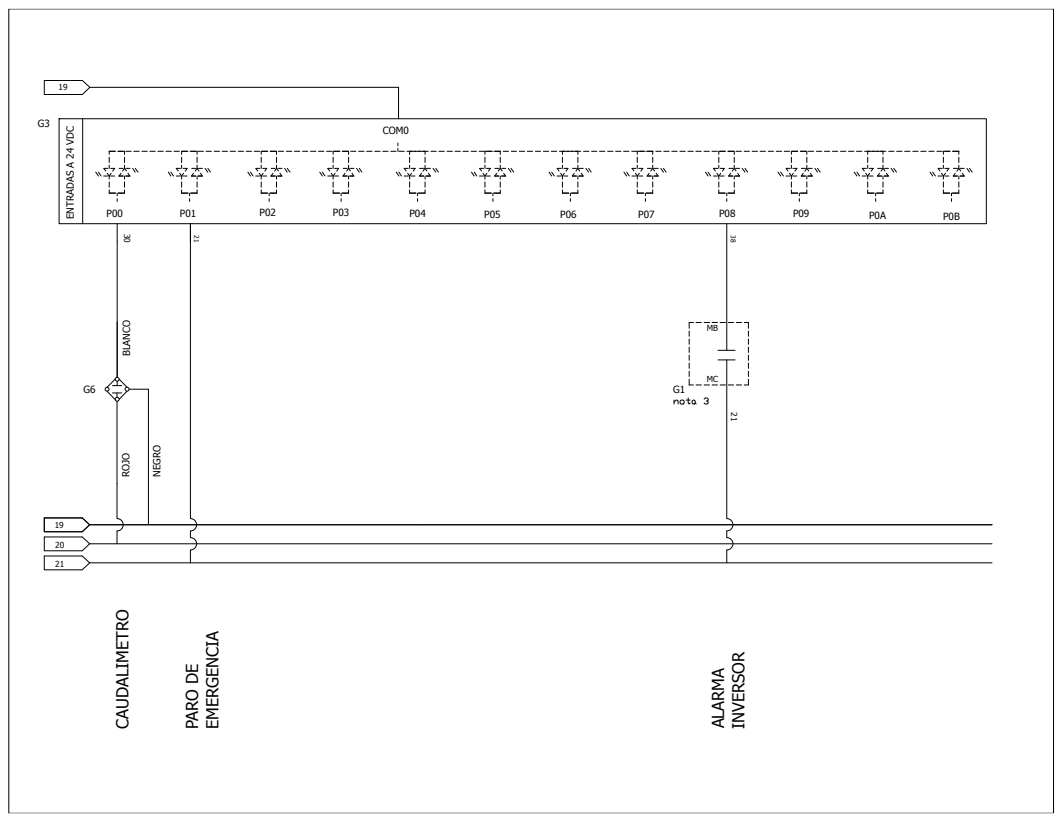
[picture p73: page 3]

## 21 SALIDAS RELEVADOR

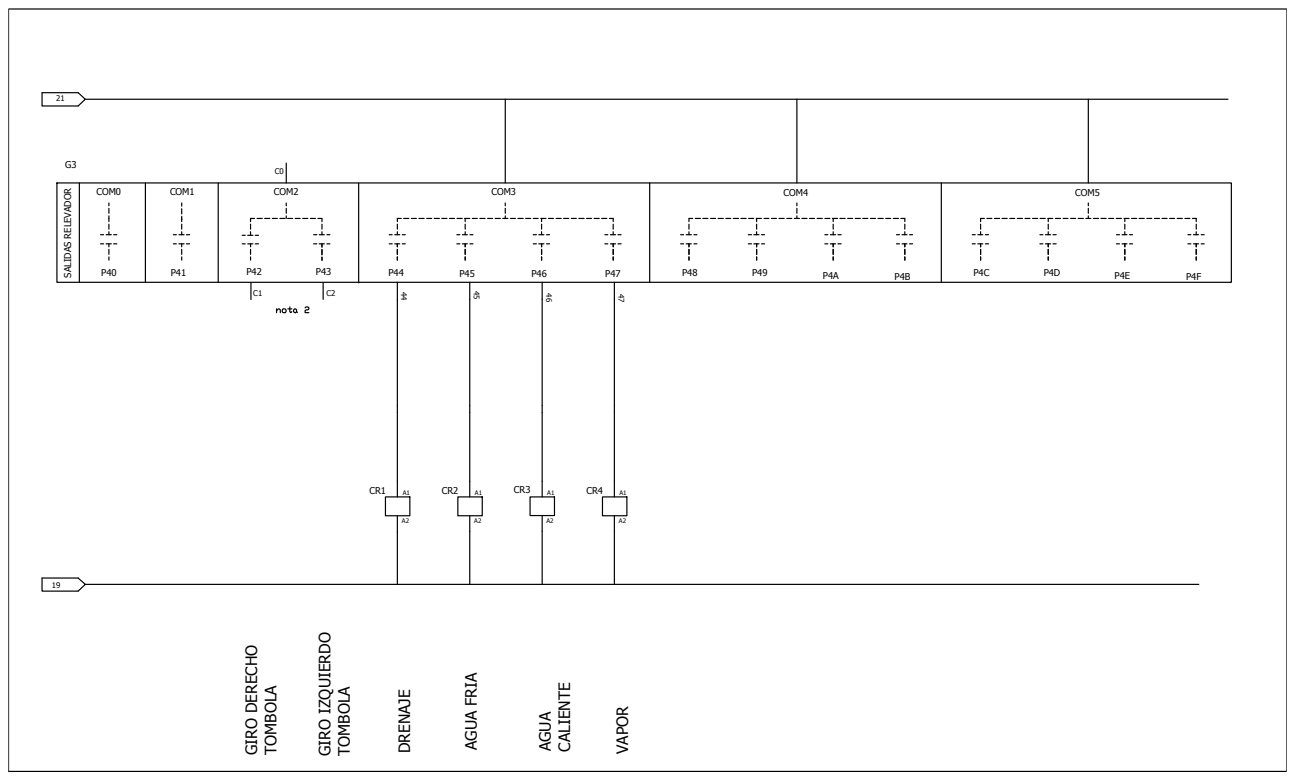
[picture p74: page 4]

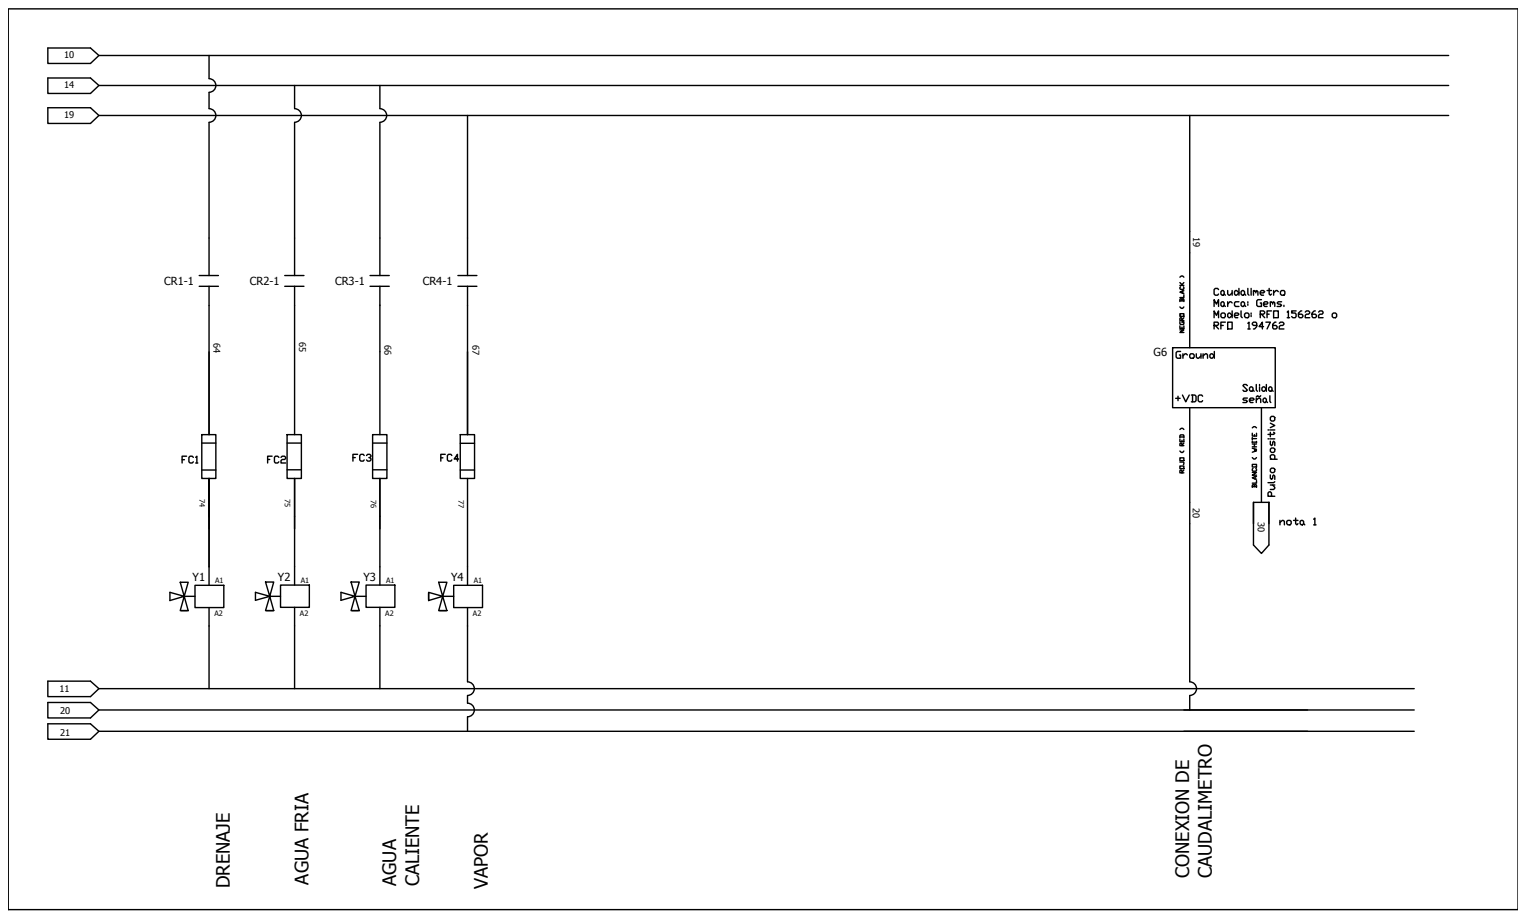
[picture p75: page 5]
DRENAJE; AGUA FRIA; AGUA; CALIENTE; VAPOR; CONEXION DE; CAUDALIMETRO

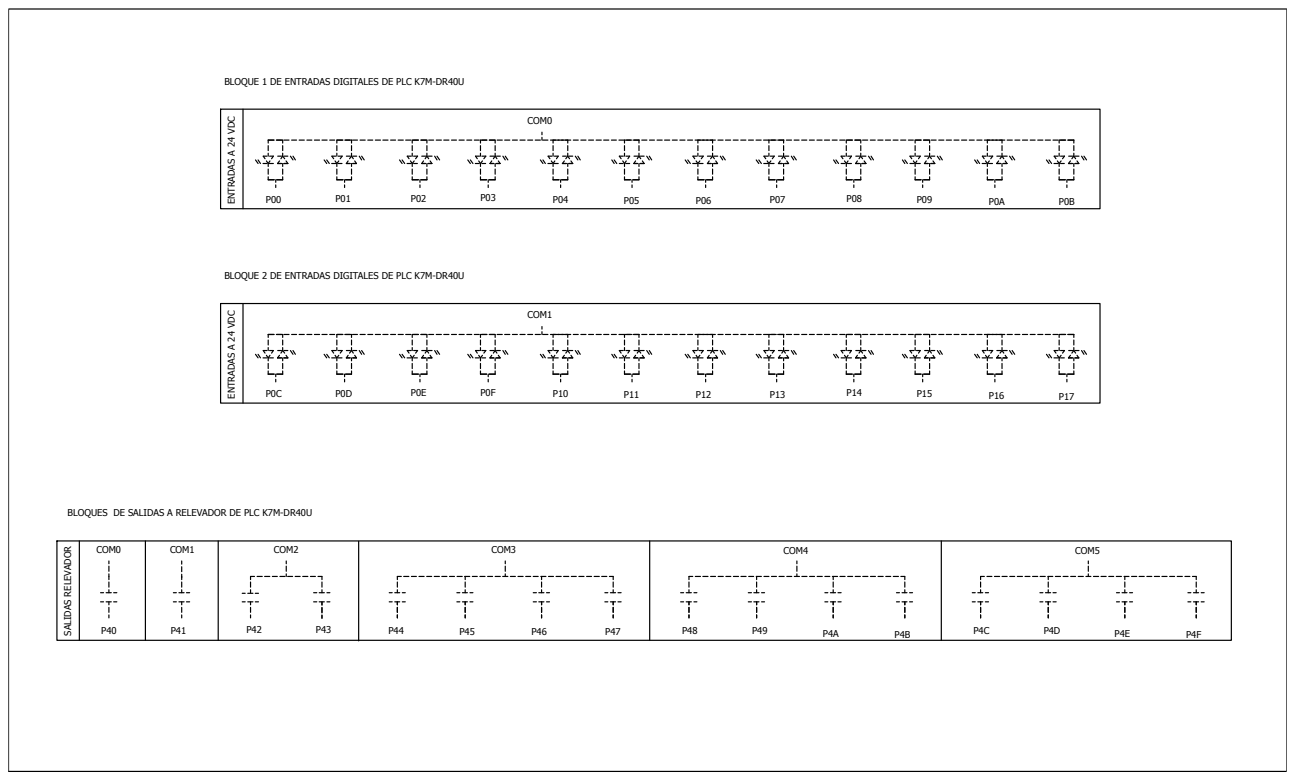
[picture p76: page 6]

BLOQUE 1 DE ENTRADAS DIGITALES DE PLC K7M-DR40U

BLOQUE 2 DE ENTRADAS DIGITALES DE PLC K7M-DR40U

BLOQUES DE SALIDAS A RELEVADOR DE PLC K7M-DR40U

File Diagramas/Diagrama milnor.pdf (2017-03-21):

FG | 24V | A | b | B

MOD: G7F-RD2A, MARCA: LS

MODULO RTD

-RS485 + | PLC MOD: K7M-DR40U MARCA: LS | 24G | 24V

### SALIDA

### MOD: DOP-B05S111 MARCA: DELTA

ELECTRONICS, INC.

+24V | PANTALLA TACTIL
19 | 0V

20

EQUIPO:

Equipo: Lavadora Textil
Marca: Milnor
Modelo:
Maquina: Milnor, Laboratorio Teñido

Representa cable.

Representa Borna de conexion.

Lista de dispositivos instalados:
1 pza. PLC Marca: Ls, Modelo: K7M-DR40U
1 pza. Modulo analogo marca: Ls, Modelo: G7F-RD2A.
1 pza. Pantalla Tactil Marca: Delta electronics,inc. modelo: DOP-B05S111 1 pza. Fuente de alimentacion con salida a 24 VDC, 5 Amps.

NOTAS:

PROYECTO:

Adaptacion de sistema de control con PLC Marca: Ls y pantalla tactil Marca: Delta Electronics, inc.

o xx xx

xx

A | b | A | b
B | B | .
CH0 | CH1
24G | B | A CH3 | b CH2

RS232

2

3
5

7
4

5

Los voltajes opcionales de fuente.
Son por posibles cambios en la alimentacion de dispositivos, como por ejemplo: Bobinas de contactores, bobinas de electrovalvulas, etc. de ser así, hacer los cambios correspondientes.

G2

G3 | G4

G4

G1 Variador de velocidad.
G2 Pantalla HMI.
G3 PLC.
G4 Modulo Temperatura PLC. G5 Fuente de alimentacion. G6 Caudalimetro.

101

100

### AC 100-240V

11

10

## 20 ENTRADAS A ²⁴ VDC

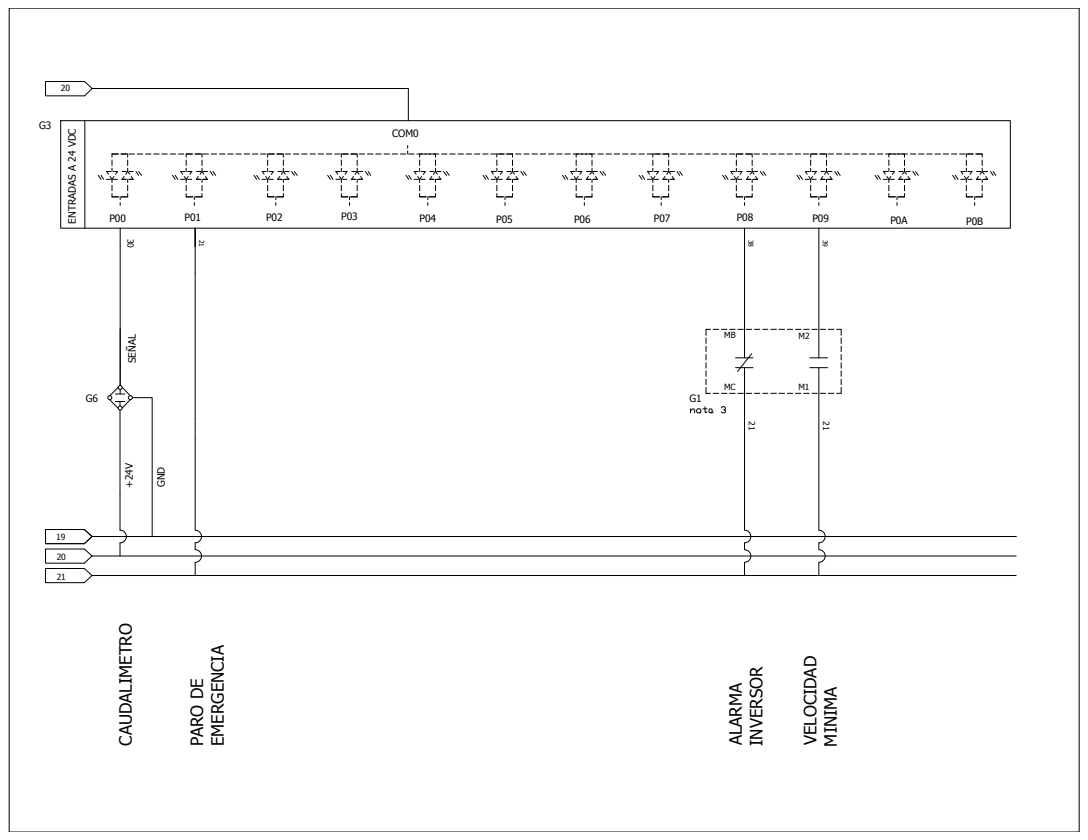
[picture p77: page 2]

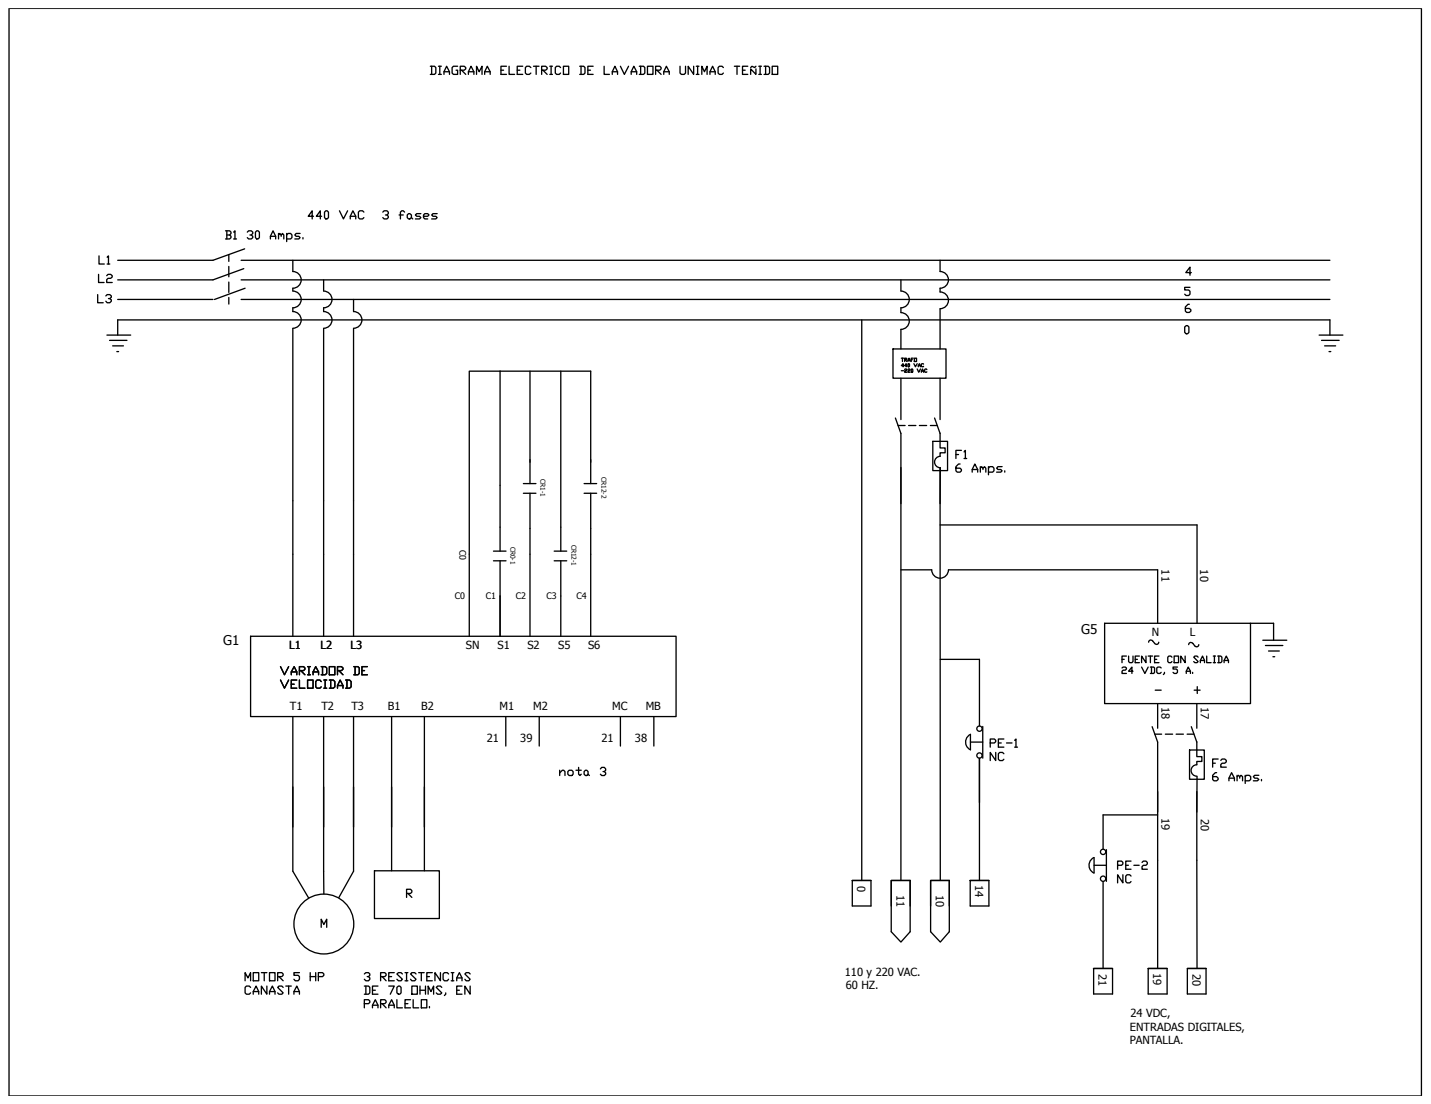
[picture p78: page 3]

## 21 SALIDAS RELEVADOR

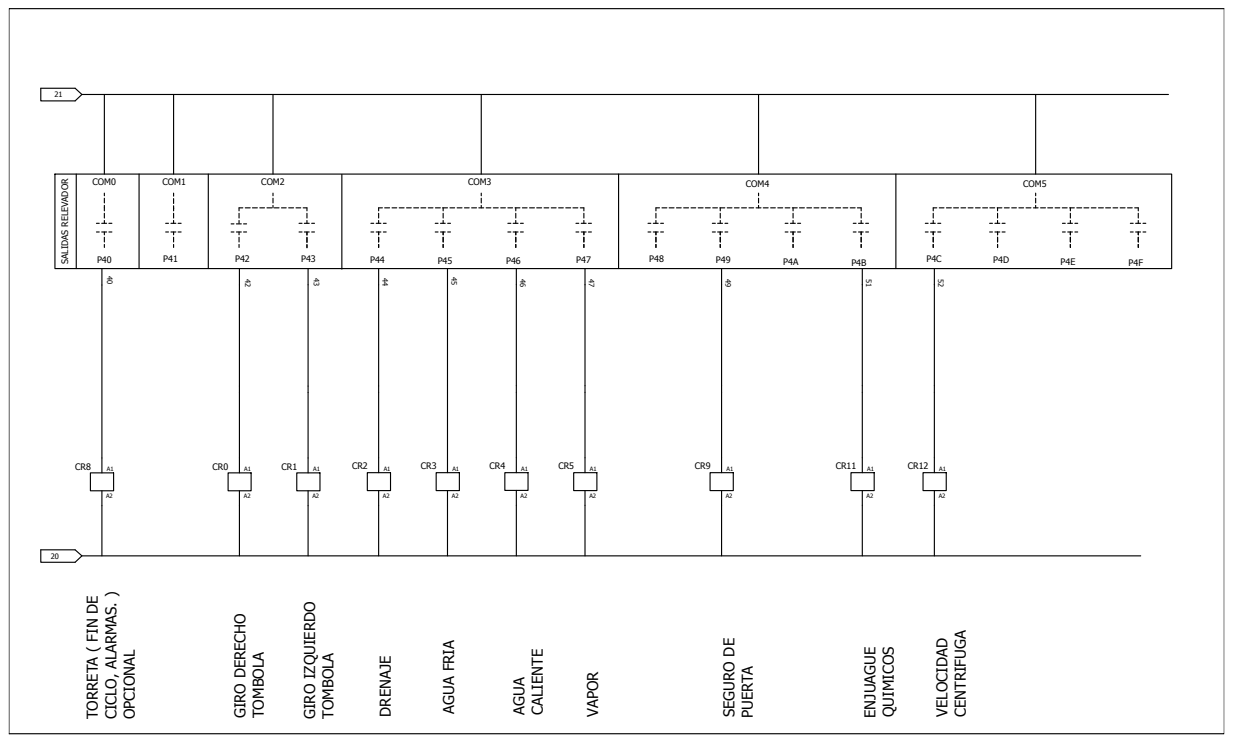
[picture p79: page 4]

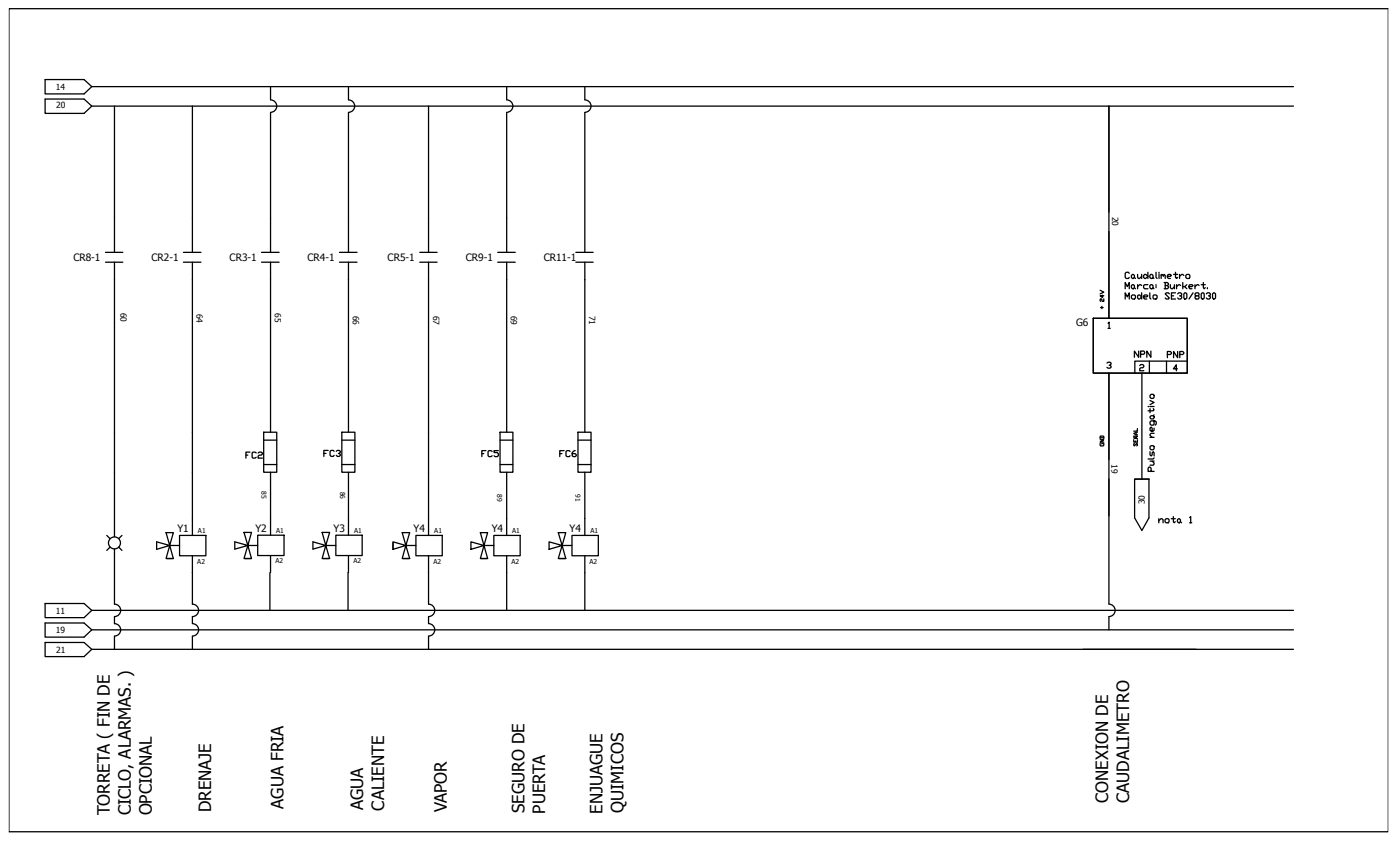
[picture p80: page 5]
CICLO, ALARMAS. ); OPCIONAL; DRENAJE; AGUA FRIA; AGUA; CALIENTE; VAPOR; SEGURO DE; PUERTA; ENJUAGUE; QUIMICOS; CONEXION DE; CAUDALIMETRO

TORRETA ( FIN DE

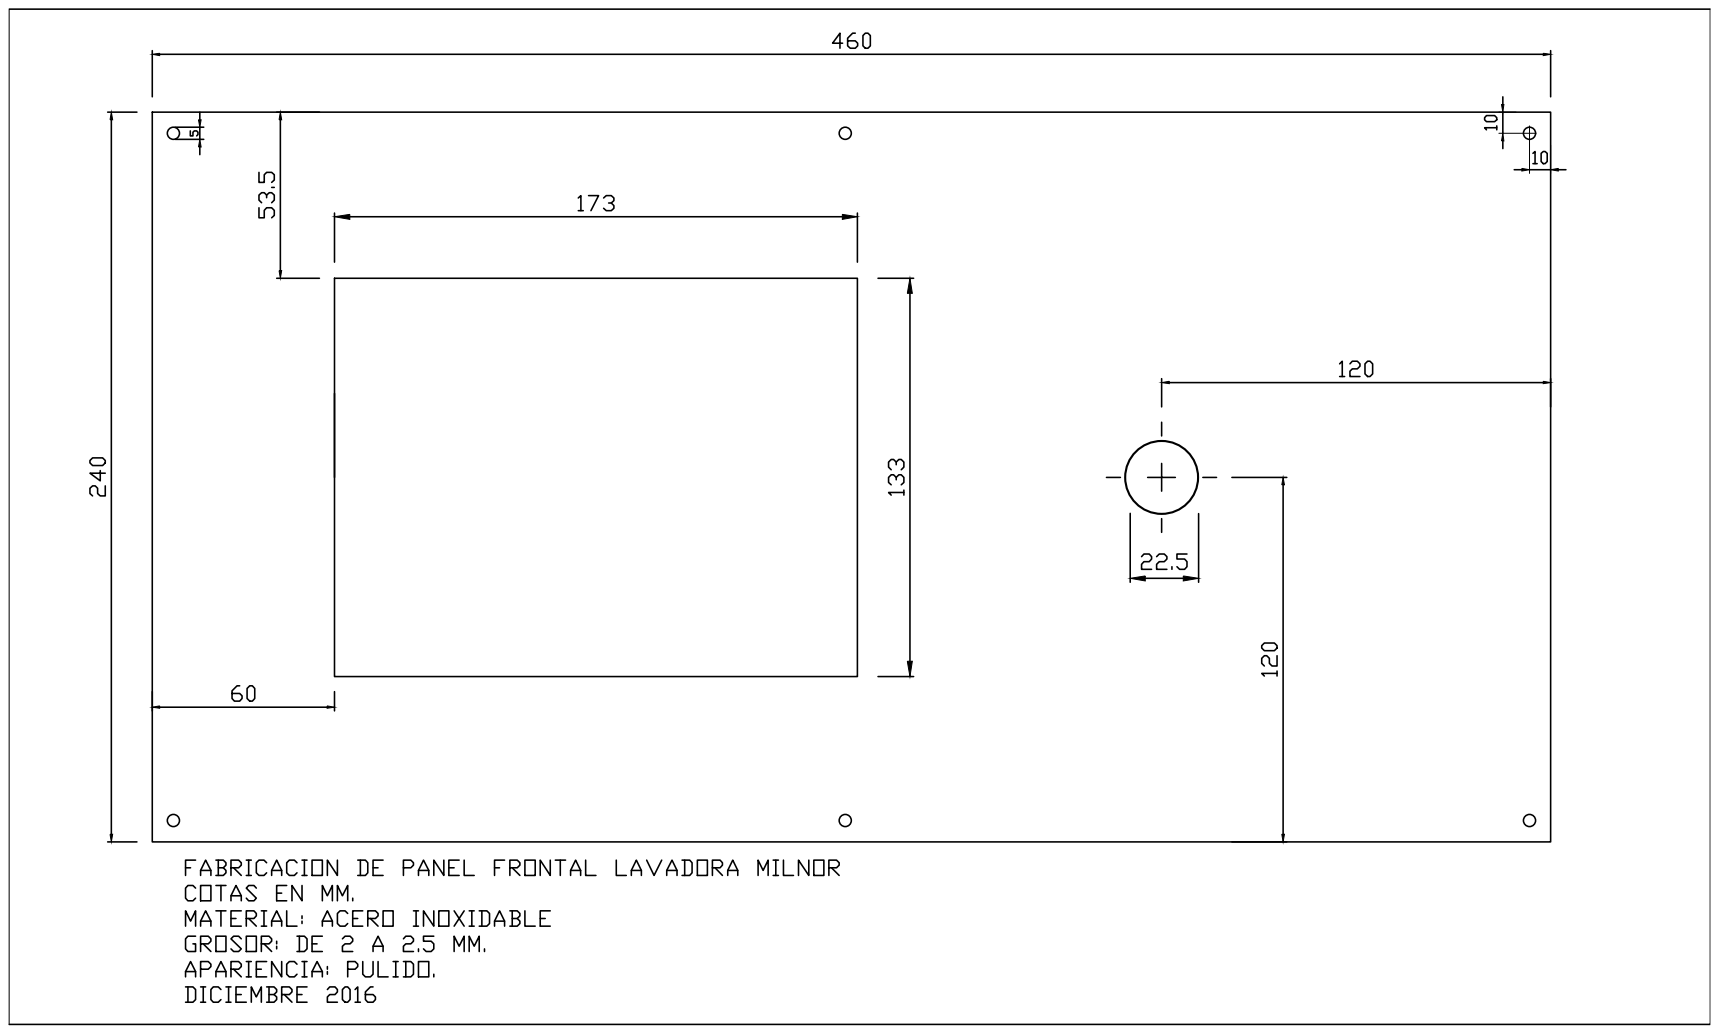
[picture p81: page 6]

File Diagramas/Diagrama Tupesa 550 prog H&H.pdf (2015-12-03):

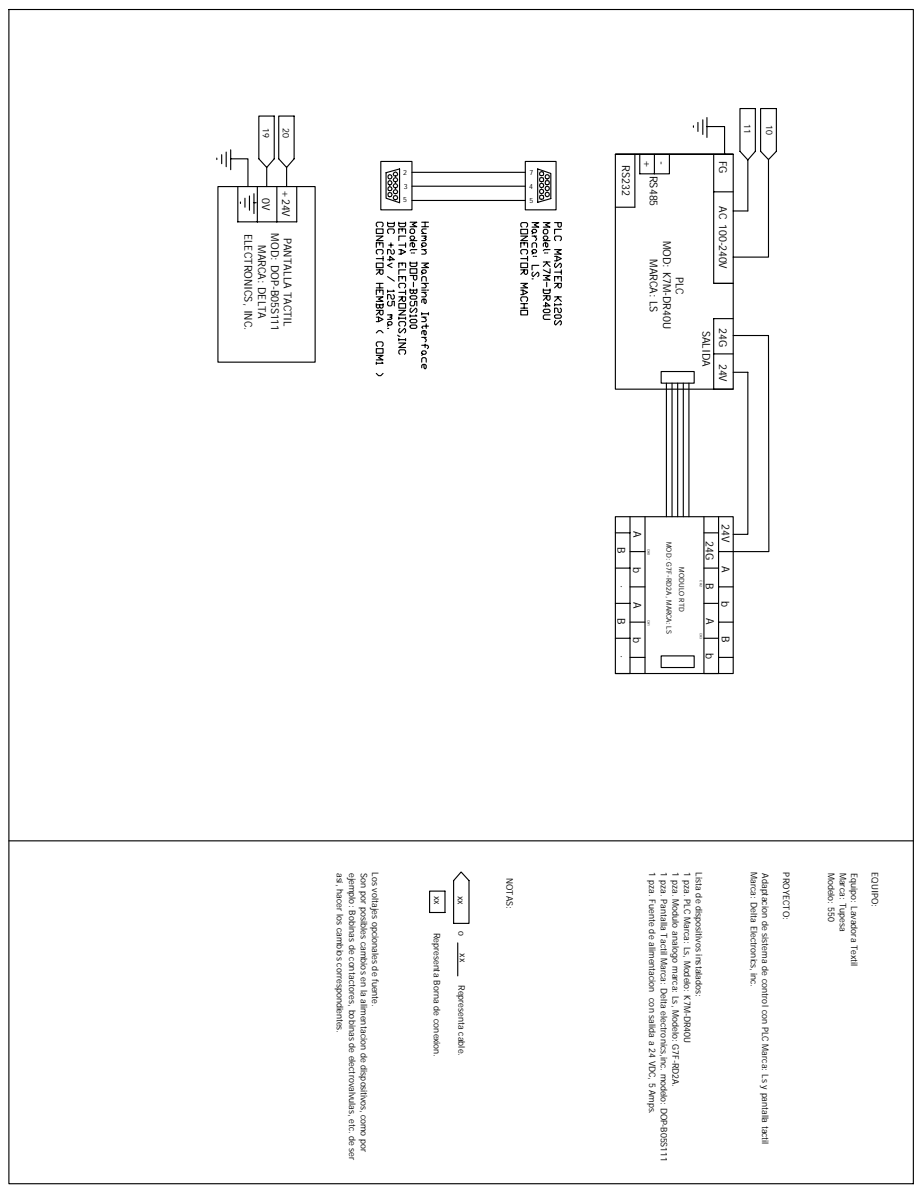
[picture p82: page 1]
MODULO RTD; MOD: K7M-DR40U MARCA: LS; PLC; SALIDA; MOD: DOP-B05S111 MARCA: DELTA; ELECTRONICS, INC.; PANTALLA TACTIL +24V; Modelo: 550; Marca: Tupesa; EQUIPO:; Representa cable.; NOTAS:; PROYECTO:

MOD: G7F-RD2A, MARCA: LS

1 pza. Fuente de alimentacion con salida a 24 VDC, 5 Amps.

1 pza. Pantalla Tactil Marca: Delta electronics,inc. modelo: DOP-B05S111

1 pza. Modulo analogo marca: Ls, Modelo: G7F-RD2A.

1 pza. PLC Marca: Ls, Modelo: K7M-DR40U

así, hacer los cambios correspondientes.

ejemplo: Bobinas de contactores, bobinas de electrovalvulas, etc. de ser

Son por posibles cambios en la alimentacion de dispositivos, como por

Los voltajes opcionales de fuente.

Lista de dispositivos instalados:

Marca: Delta Electronics, inc.

Adaptacion de sistema de control con PLC Marca: Ls y pantalla tactil

Equipo: Lavadora Textil

Representa Borna de conexion.

SALIDAS RELEVADOR P4B P4A | COM4 COM0 COM1 P4C P4D P4F P4E | COM5

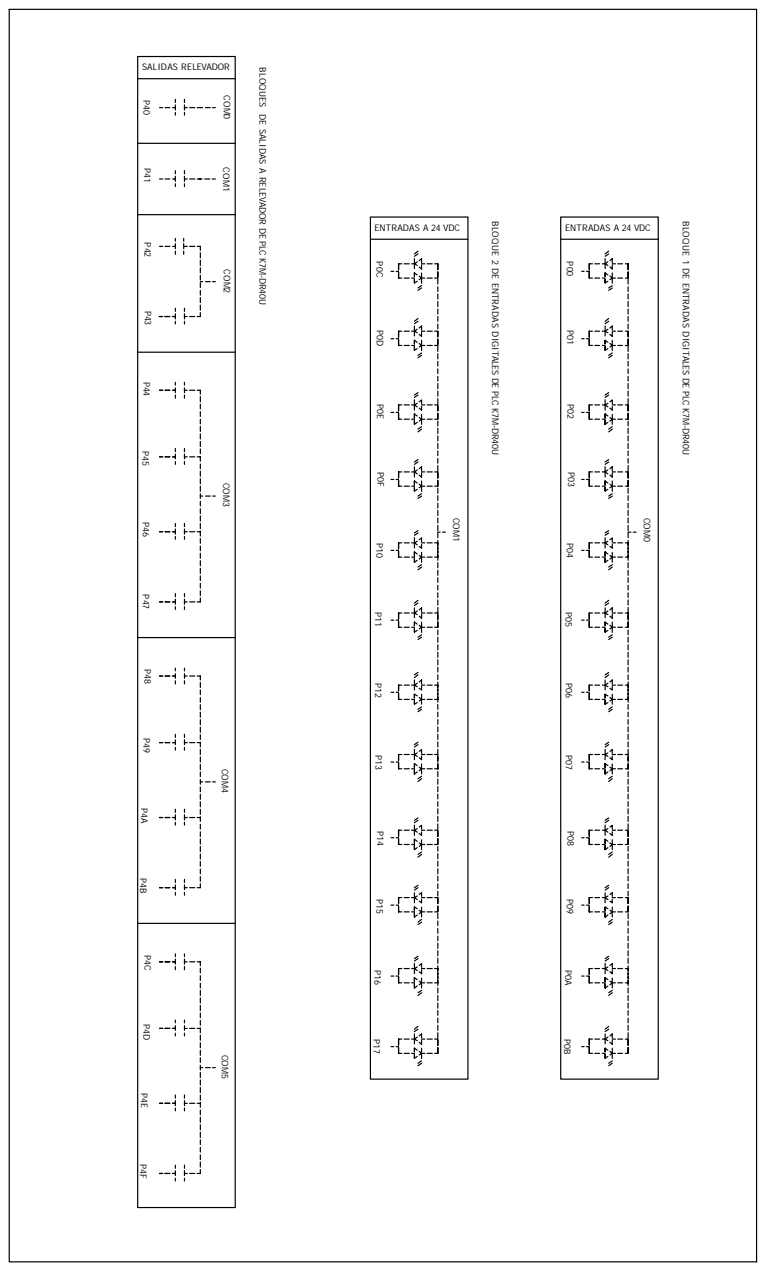
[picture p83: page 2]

BLOQUES DE SALIDAS A RELEVADOR DE PLC K7M-DR40U

BLOQUE 2 DE ENTRADAS DIGITALES DE PLC K7M-DR40U

BLOQUE 1 DE ENTRADAS DIGITALES DE PLC K7M-DR40U


OPCIONAL; 220 VAC, 60 HZ.; CONTACTORES; 24 VAC, 60 HZ.; ELECTROVALVULAS; 30 VDC; PANTALLA; ENTRADAS DIGITALES,; 24 VDC,; 110 VAC, 60 HZ.

# CUENTALITROS

# PARO DE


COM0; XXX XXX; DRENAJE; AGUA FRIA; AGUA CALIENTE; VAPOR; PLC MASTER K120S; ENTRADAS SALIDAS; COM3; MOD: K7M-DR40U MARCA: LS; COM4; MAQUINA HORIZONTAL

XXX XXX XXX XXX P44 P45 P46 P47

# ALIMENTACION PANTALLA

ALIMENTACION MODULO DE TEMPERATURA; ALIMENTACION DE CAUDALIMETRO

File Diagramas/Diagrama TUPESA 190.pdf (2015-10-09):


220 VAC, 60 HZ. PLC; 24 VAC, 60 HZ. CONTACTORES; 30 VDC ELECTROVALVULAS; 24 VDC, ENTRADAS DIGITALES, PANTALLA



VOLQUETE HORIZONTAL; VOLQUETE DESCARGA; CABLE DE COMUNICACION SERIAL; ALIMENTACION PANTALLA; ALIMENTACION MODULO DE TEMPERATURA; ALIMENTACION DE CAUDALIMETRO





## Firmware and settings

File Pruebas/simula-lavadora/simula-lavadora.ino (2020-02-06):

#include <Wire.h>

byte x = 255;
int temperatura=20;
byte inclinacion = 0;
int vapor;
int volquete;
boolean cambio;

void setup()
{
	Wire.begin();
	pinMode(2,INPUT_PULLUP);
	pinMode(3,INPUT_PULLUP);
	pinMode(4,INPUT_PULLUP);
	pinMode(5,INPUT_PULLUP);
	pinMode(6,INPUT_PULLUP);
	pinMode(13,OUTPUT);
}

void loop()
{
	delay(50);
	digitalWrite(13, LOW);
	cambio = false;
	// Subir
	if (digitalRead(5)==LOW)
	{
		volquete++;
		if (volquete > 5)
		{
			volquete=0;
			if ( inclinacion > 0 )
			{
				inclinacion--;
				cambio=true;
			}
		}
	}
	// Bajar
	if (digitalRead(6)==LOW)  
	{
		volquete++;
		if (volquete > 3)
		{
			volquete=0;
			if ( inclinacion < 250 )
			{
				inclinacion++;
				cambio=true;
			}
		}
	}
	// Vapor
	if (digitalRead(4) == LOW)
	{
		vapor++;
		if (vapor >= 20)
		{
			vapor=0;
			if (temperatura < 255)
			{
				temperatura++;
				cambio=true;
			}
		}
	}
	else
	{
		vapor++;
		if (vapor >= 100)
		{
			vapor=0;
			if (temperatura > 10)
			{
				temperatura--;
			}
		}
	}
	// Agua fria o caliente
	if (digitalRead(3)==LOW)
	{
		if (bitRead(x,0)==0)
		{
			bitSet(x,0);
		}
		else
		{
			bitClear(x,0);
		}
		cambio=true;
	}
	// Desague
	if (digitalRead(2)==LOW)
	{
		vapor++;
		if (vapor >= 5)
		{
			vapor=0; 
			if (temperatura > 10)
			{
				temperatura--;
				cambio=true;
			}
		}
	}
	if ((inclinacion >= 120 ) && (inclinacion <= 140))
	{
		bitClear(x,1);
	}
	else
	{
		bitSet(x,1);
	}
	
	analogWrite(11,temperatura);
	if (cambio)
	{
		delay(50);
		digitalWrite(13, HIGH);
	}
	Wire.beginTransmission(39);
	Wire.write(x);
	Wire.endTransmission();
}

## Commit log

2015-10-09 Antes de commit inicial
2015-10-09 --- Commit inicial
    [AFOROS TUP-190.xls, entradas y salidas.xlsx, estructura paso.xlsx]
2015-10-13 Se actualiza la descripcion del proyecto.
    [estructura paso.xlsx]
2015-10-19 Se agrega previsualizacion de fotos.
2015-11-10 Se agrega foto de vista de platina
2015-11-28 * Se actualiza manual de usuario. * Se agregan capturas de pantalla.
2015-12-03 Se actualiza seccion importar/exportar en manual de usuario.
2015-12-03 Se agrega diagrama de lavadora tupesa 550 de lavapant
2015-12-21 * Se corrige error en desague manual no se programaba el tiempo de desague. * Se modifica manual de usuario (se agrega descripcion de confirmar paso).
2016-03-17 * Se agrega ejemplo de recetas * Se agrega programa de simulacion de lavadora para arduino. * Se agrega programa de simulacion de lavadora para PLC.
2016-05-28 :heavy_check_mark: Se libera version 1.01 de PLC y HMI. * Se corrijen detalles esteticos.
2016-05-31 Se corrige error no hay forma de cancelar "confirmar paso".
2016-06-16 Se libera version 1.03 de PLC y 1.02 de HMI. Se implementa #5. Se implementa #4. Se revisa #3 pero no se encontro ningun problema. Se desecha la idea #2 ya que se considera que el modulo analogo rara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
    [AFOROS TUP-190.xls]
2016-06-27 :paperclip: Se agrega diagrama de simula lavadora.
    [simula lavadora.dwg]
2016-11-16 * Se reubican botones para hacerlos mas accesibles. * Se eliminan iconos innecesarios.
2016-12-02 Se actualiza lista de entradas y salidas.
    [entradas y salidas.xlsx]
2016-12-06 Diagrama tupesa 190 ( En Acad )
    [Diagrama Tupesa 190.dwg]
2016-12-19 Se libera version 1.04 de plc y 1.04 de hmi. * Calentamiento con control proporcional.
    [entradas y salidas.xlsx, estructura paso.xlsx]
2017-01-05 Se libera version 1.05 de PLC y HMI. * Se agrega paso centrifugado (#7)
    [entradas y salidas.xlsx, estructura paso.xlsx]
2017-03-16 Modificacion lavadora unimac laboratorio de teñido.
    [Diagrama Lav. Unimac modelo UWL045K1MXU4P01. lab. Teñido.dwg]
2017-03-16 Fotos de lavadora unimac laboratorio teñido
2017-03-17 Diagrama lavadora milnor laboratorio de teñido. marzo 2017
    [Diagrama Maquina Milnor Laboratorio Teñido.dwg]
2017-03-21 Diagrama de Lavadora Milnor de teñido
    Impresión en Pdf del diagrama de lavadora milnor en autocad
2017-03-21 Diagrama de lavadora unimac
    Impresión en pdf del archivo de diagrama de lavadora unimac en autocad.
2017-05-02 Se libera version 1.06 de PLC y 1.06 de HMI.
    [entradas y salidas.xlsx]
2018-02-03 Se reorganizan archivos para diferentes versiones de HMI.
2020-02-06 Se agrega checklist de entrega y lista de parametros
    [entradas y salidas.xlsx, estructura paso.xlsx, parametros.xlsx]
